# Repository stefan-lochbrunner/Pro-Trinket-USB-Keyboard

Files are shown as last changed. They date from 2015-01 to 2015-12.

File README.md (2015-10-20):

Pro-Trinket-USB-Keyboard
========================
A small device for programmable keyboard shortcuts.
For more infos please see [**HaD.io project page**](https://hackaday.io/project/3502-pro-trinket-usb-keyboard)

keyboard

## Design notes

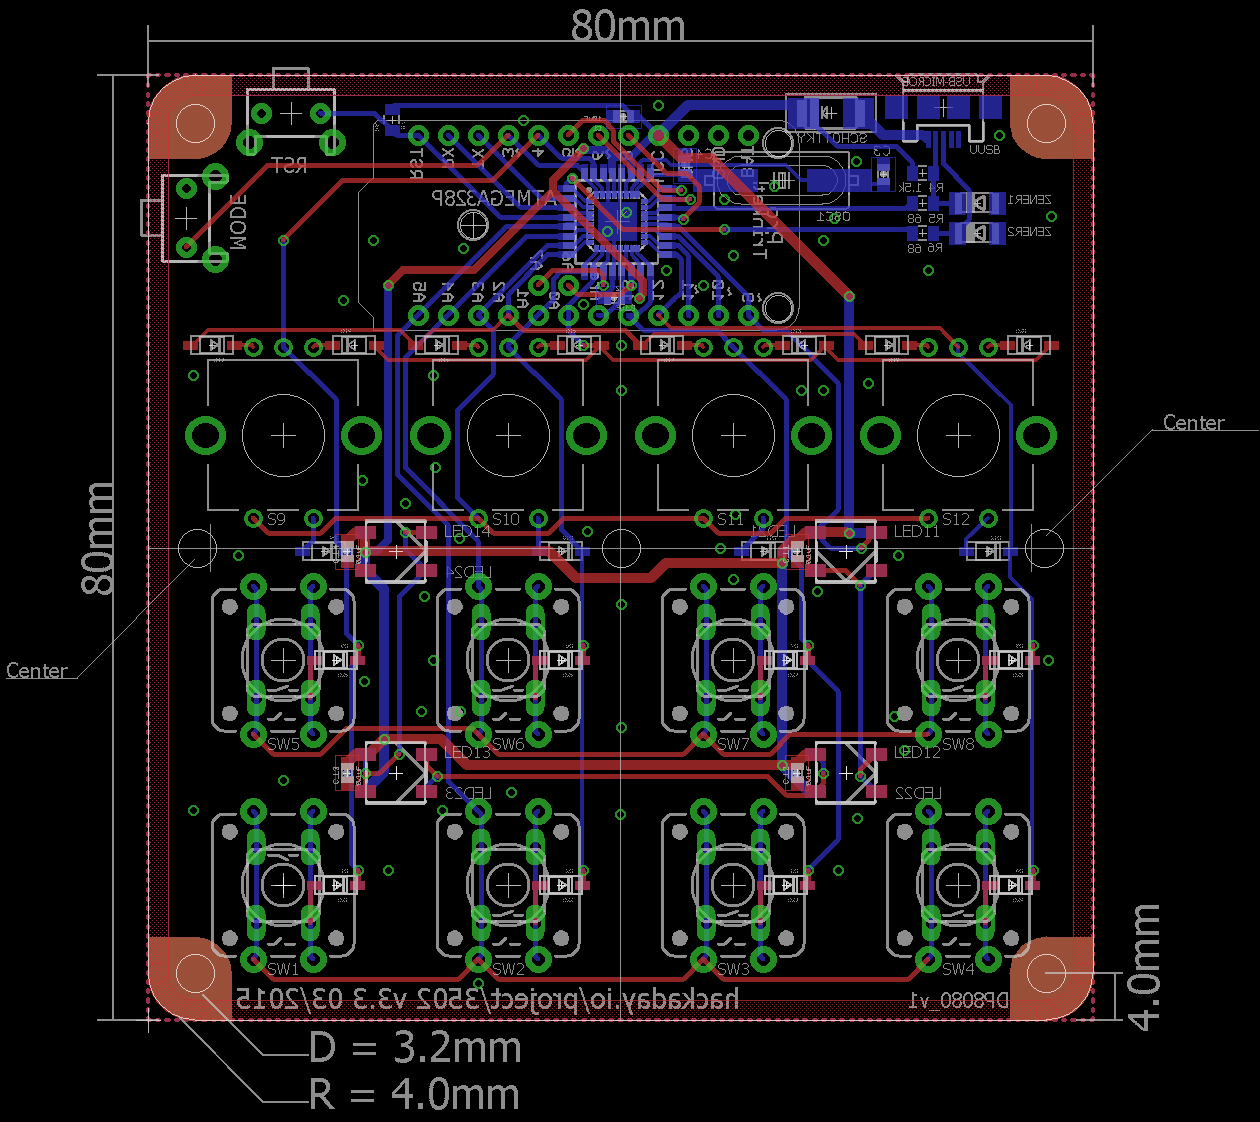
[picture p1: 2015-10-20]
Pro Trinket Keyboard/hw/schematics/Pro Trinket Keyboard V3.4.brd.png

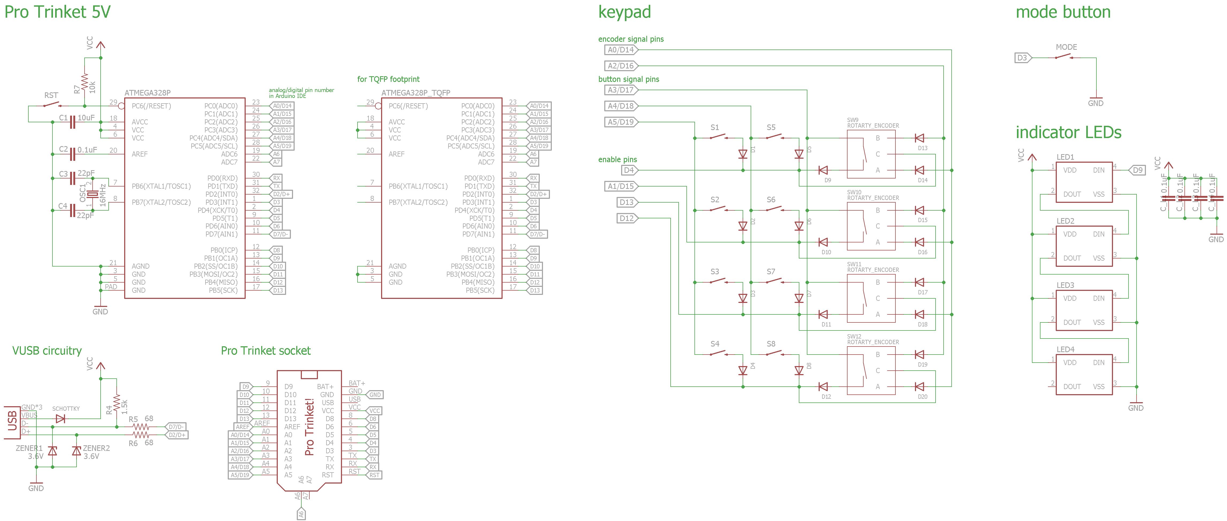
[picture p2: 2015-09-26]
Pro Trinket Keyboard/hw/schematics/Pro Trinket Keyboard V3.3.sch.png

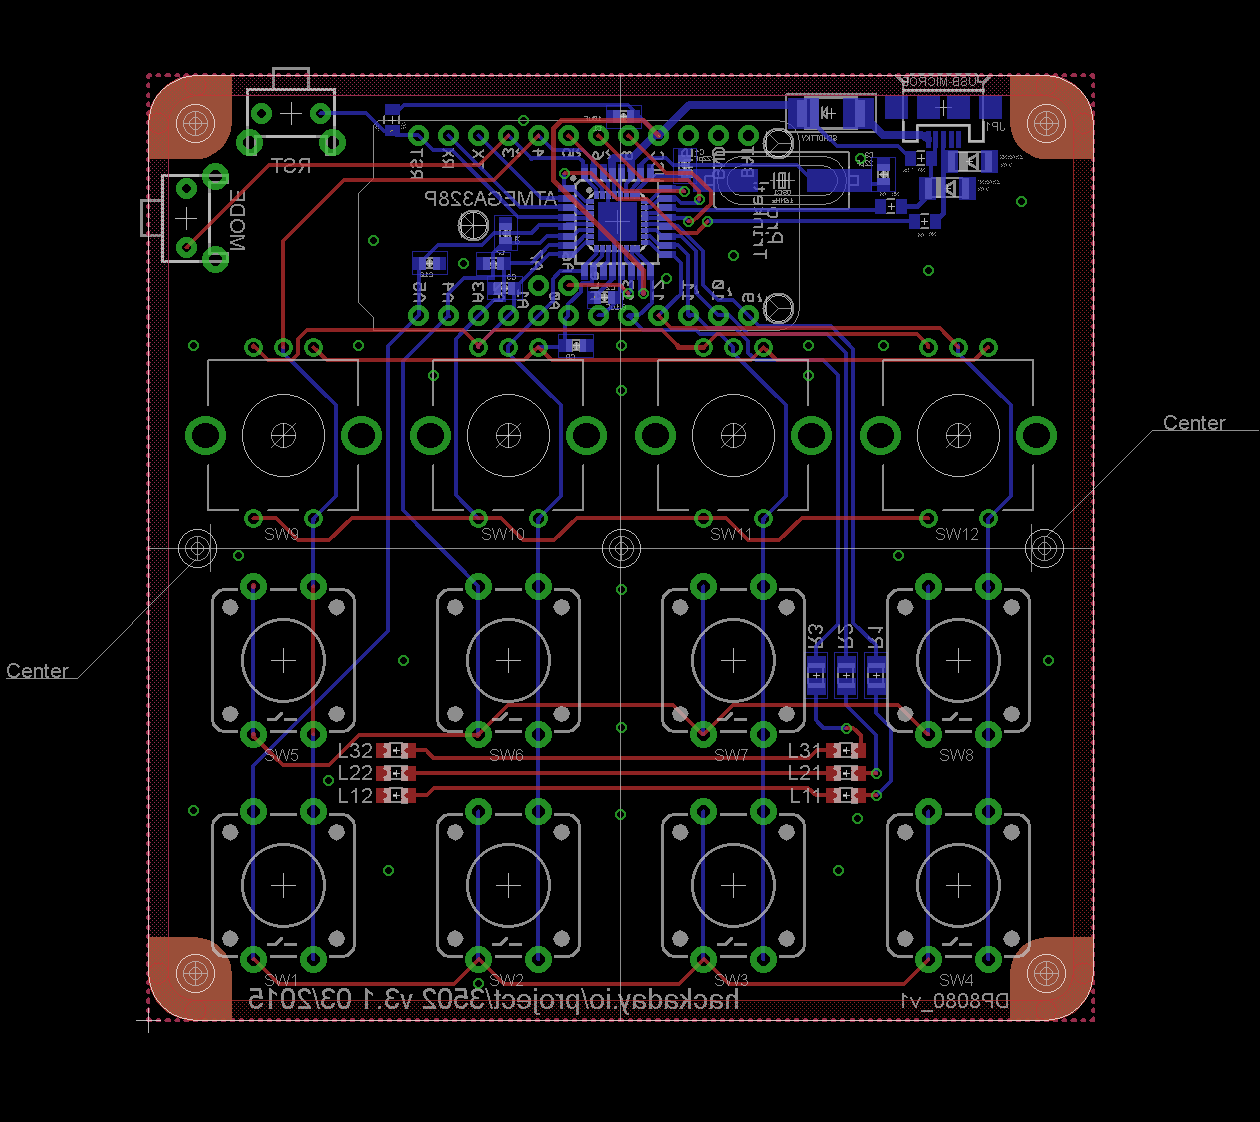
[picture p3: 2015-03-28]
Pro Trinket Keyboard/hw/schematics/Pro Trinket Keyboard V3.1.brd.png

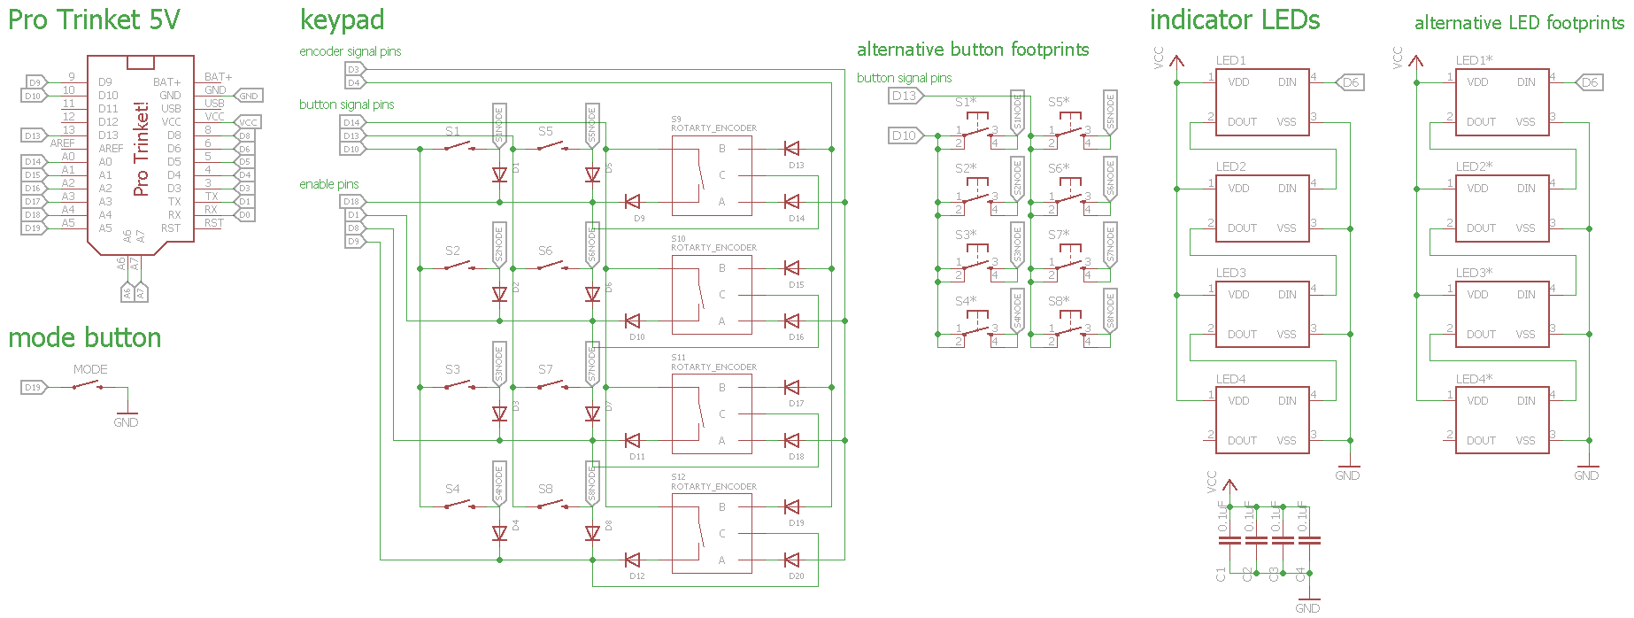
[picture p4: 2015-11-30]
Pro Trinket Keyboard/hw/schematics/Pro Trinket Keyboard V4.0.sch.png

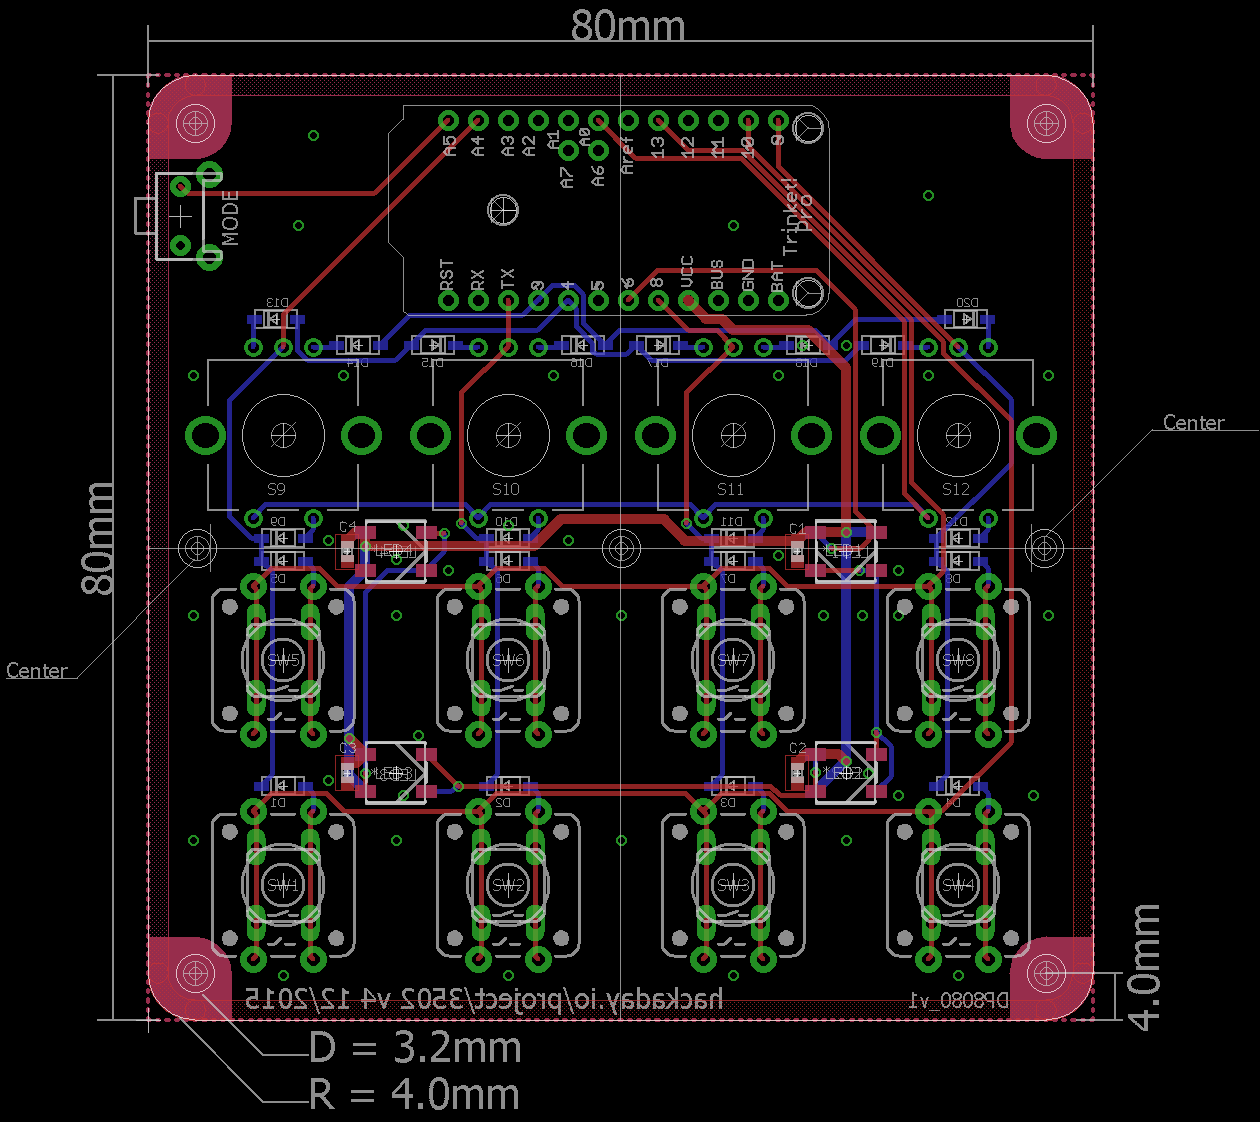
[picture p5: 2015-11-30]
Pro Trinket Keyboard/hw/schematics/Pro Trinket Keyboard V4.0.brd.png

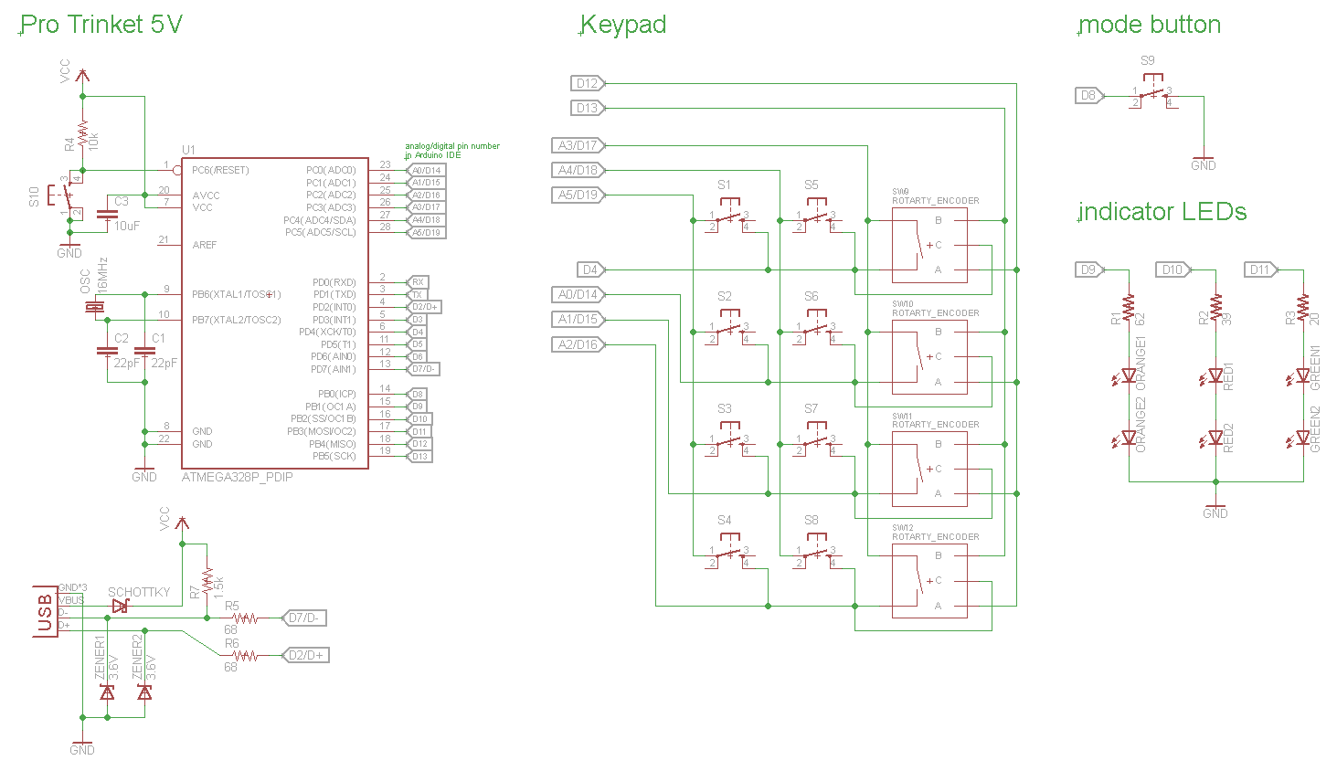
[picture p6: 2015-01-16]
Pro Trinket Keyboard/hw/schematics/Pro Trinket Keyboard V2.png

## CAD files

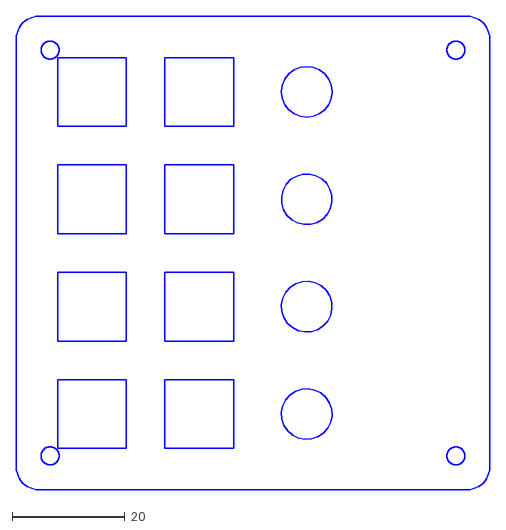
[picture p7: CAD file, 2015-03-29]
Pro Trinket Keyboard/hw/case/SoBv1-DP8080-case-top.dxf
84.0 x 84.0

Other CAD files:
Pro Trinket Keyboard/hw/case/SoBv1-DP8080-case-top.skp
Pro Trinket Keyboard/hw/case/SoBv1-DP8080-template.skp

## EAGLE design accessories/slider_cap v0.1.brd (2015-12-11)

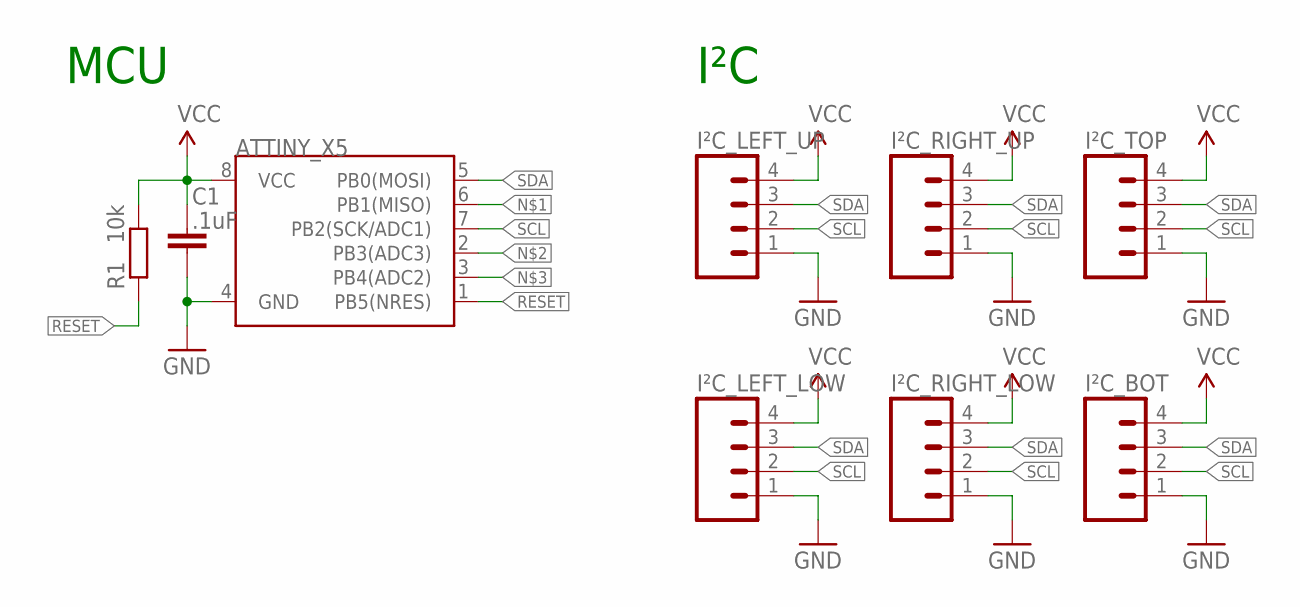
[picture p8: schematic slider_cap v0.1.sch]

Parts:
ATTINY_X5: ATTINY45TINY45-20-SMT; SO08-EIAJ
C1: .1uF; C805
I²C_BOT: M04PTH; 1X04
I²C_LEFT_LOW: M04PTH; 1X04
I²C_LEFT_UP: M04PTH; 1X04
I²C_RIGHT_LOW: M04PTH; 1X04
I²C_RIGHT_UP: M04PTH; 1X04
I²C_TOP: M04PTH; 1X04
R1: 10k; R805

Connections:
GND: ATTINY_X5.4 (GND), C1.2, I²C_BOT.1, I²C_LEFT_LOW.1, I²C_LEFT_UP.1, I²C_RIGHT_LOW.1, I²C_RIGHT_UP.1, I²C_TOP.1
RESET: ATTINY_X5.1 (PB5(NRES)), R1.1
SCL: ATTINY_X5.7 (PB2(SCK/ADC1)), I²C_BOT.2, I²C_LEFT_LOW.2, I²C_LEFT_UP.2, I²C_RIGHT_LOW.2, I²C_RIGHT_UP.2, I²C_TOP.2
SDA: ATTINY_X5.5 (PB0(MOSI)), I²C_BOT.3, I²C_LEFT_LOW.3, I²C_LEFT_UP.3, I²C_RIGHT_LOW.3, I²C_RIGHT_UP.3, I²C_TOP.3
VCC: ATTINY_X5.8 (VCC), C1.1, I²C_BOT.4, I²C_LEFT_LOW.4, I²C_LEFT_UP.4, I²C_RIGHT_LOW.4, I²C_RIGHT_UP.4, I²C_TOP.4, R1.2

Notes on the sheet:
I²C
MCU

Board: 2 copper layers, 9 parts (3 on the bottom side), 5 nets, no tracks yet.

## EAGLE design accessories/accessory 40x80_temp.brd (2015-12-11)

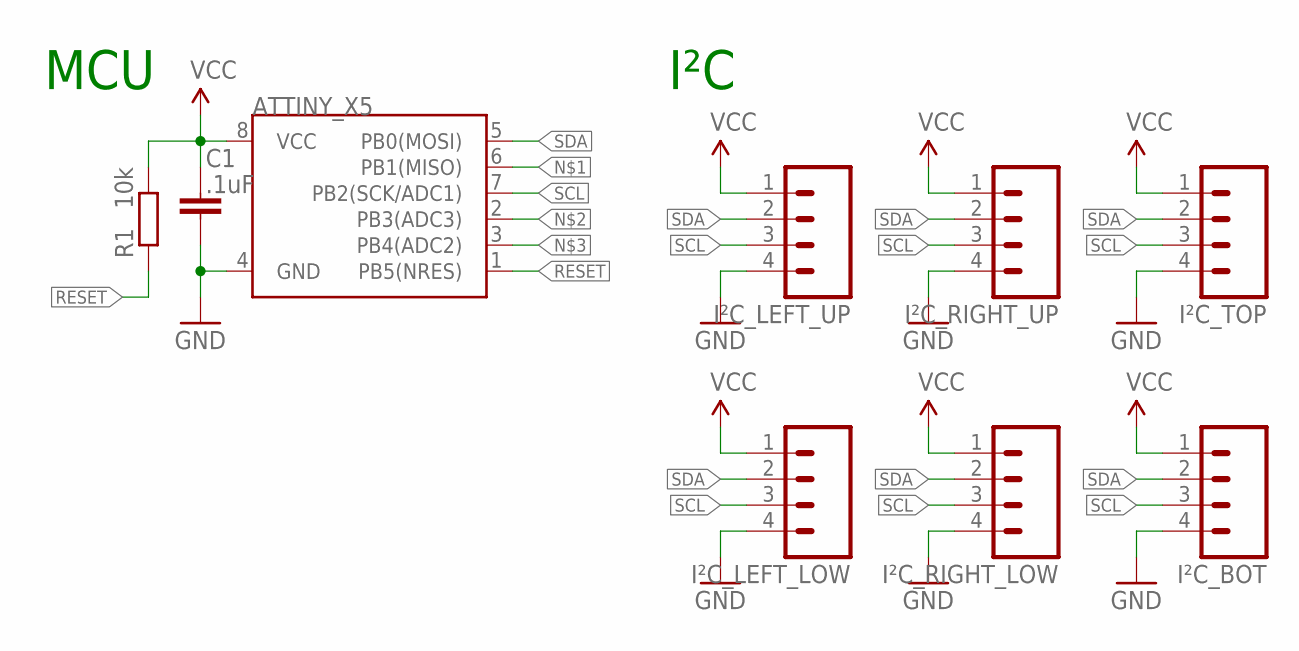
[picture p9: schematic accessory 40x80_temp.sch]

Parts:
ATTINY_X5: ATTINY45TINY45-20-SMT; SO08-EIAJ
C1: .1uF; C805
I²C_BOT: M04PTH; 1X04
I²C_LEFT_LOW: M04PTH; 1X04
I²C_LEFT_UP: M04PTH; 1X04
I²C_RIGHT_LOW: M04PTH; 1X04
I²C_RIGHT_UP: M04PTH; 1X04
I²C_TOP: M04PTH; 1X04
R1: 10k; R805

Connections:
GND: ATTINY_X5.4 (GND), C1.2, I²C_BOT.4, I²C_LEFT_LOW.4, I²C_LEFT_UP.4, I²C_RIGHT_LOW.4, I²C_RIGHT_UP.4, I²C_TOP.4
RESET: ATTINY_X5.1 (PB5(NRES)), R1.1
SCL: ATTINY_X5.7 (PB2(SCK/ADC1)), I²C_BOT.3, I²C_LEFT_LOW.3, I²C_LEFT_UP.3, I²C_RIGHT_LOW.3, I²C_RIGHT_UP.3, I²C_TOP.3
SDA: ATTINY_X5.5 (PB0(MOSI)), I²C_BOT.2, I²C_LEFT_LOW.2, I²C_LEFT_UP.2, I²C_RIGHT_LOW.2, I²C_RIGHT_UP.2, I²C_TOP.2
VCC: ATTINY_X5.8 (VCC), C1.1, I²C_BOT.1, I²C_LEFT_LOW.1, I²C_LEFT_UP.1, I²C_RIGHT_LOW.1, I²C_RIGHT_UP.1, I²C_TOP.1, R1.2

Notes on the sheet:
I²C
MCU

Board: 2 copper layers, 9 parts (3 on the bottom side), 5 nets, no tracks yet.

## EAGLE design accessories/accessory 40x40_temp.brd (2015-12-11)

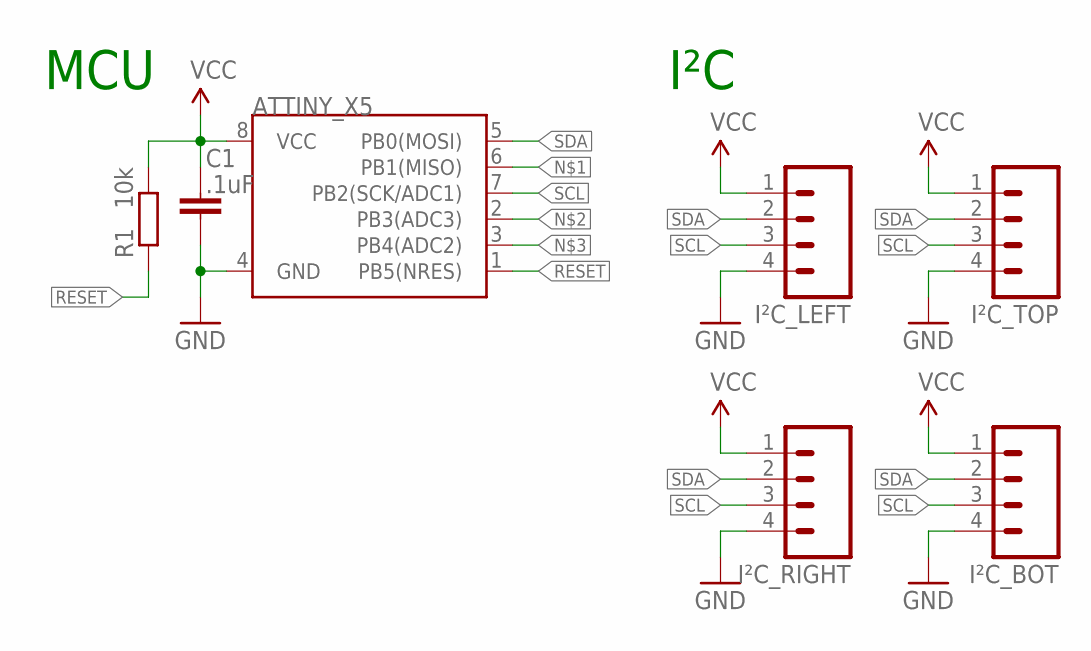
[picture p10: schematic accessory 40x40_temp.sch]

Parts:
ATTINY_X5: ATTINY45TINY45-20-SMT; SO08-EIAJ
C1: .1uF; C805
I²C_BOT: M04PTH; 1X04
I²C_LEFT: M04PTH; 1X04
I²C_RIGHT: M04PTH; 1X04
I²C_TOP: M04PTH; 1X04
R1: 10k; R805

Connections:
GND: ATTINY_X5.4 (GND), C1.2, I²C_BOT.4, I²C_LEFT.4, I²C_RIGHT.4, I²C_TOP.4
RESET: ATTINY_X5.1 (PB5(NRES)), R1.1
SCL: ATTINY_X5.7 (PB2(SCK/ADC1)), I²C_BOT.3, I²C_LEFT.3, I²C_RIGHT.3, I²C_TOP.3
SDA: ATTINY_X5.5 (PB0(MOSI)), I²C_BOT.2, I²C_LEFT.2, I²C_RIGHT.2, I²C_TOP.2
VCC: ATTINY_X5.8 (VCC), C1.1, I²C_BOT.1, I²C_LEFT.1, I²C_RIGHT.1, I²C_TOP.1, R1.2

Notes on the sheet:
I²C
MCU

Board: 2 copper layers, 7 parts (3 on the bottom side), 5 nets, no tracks yet.

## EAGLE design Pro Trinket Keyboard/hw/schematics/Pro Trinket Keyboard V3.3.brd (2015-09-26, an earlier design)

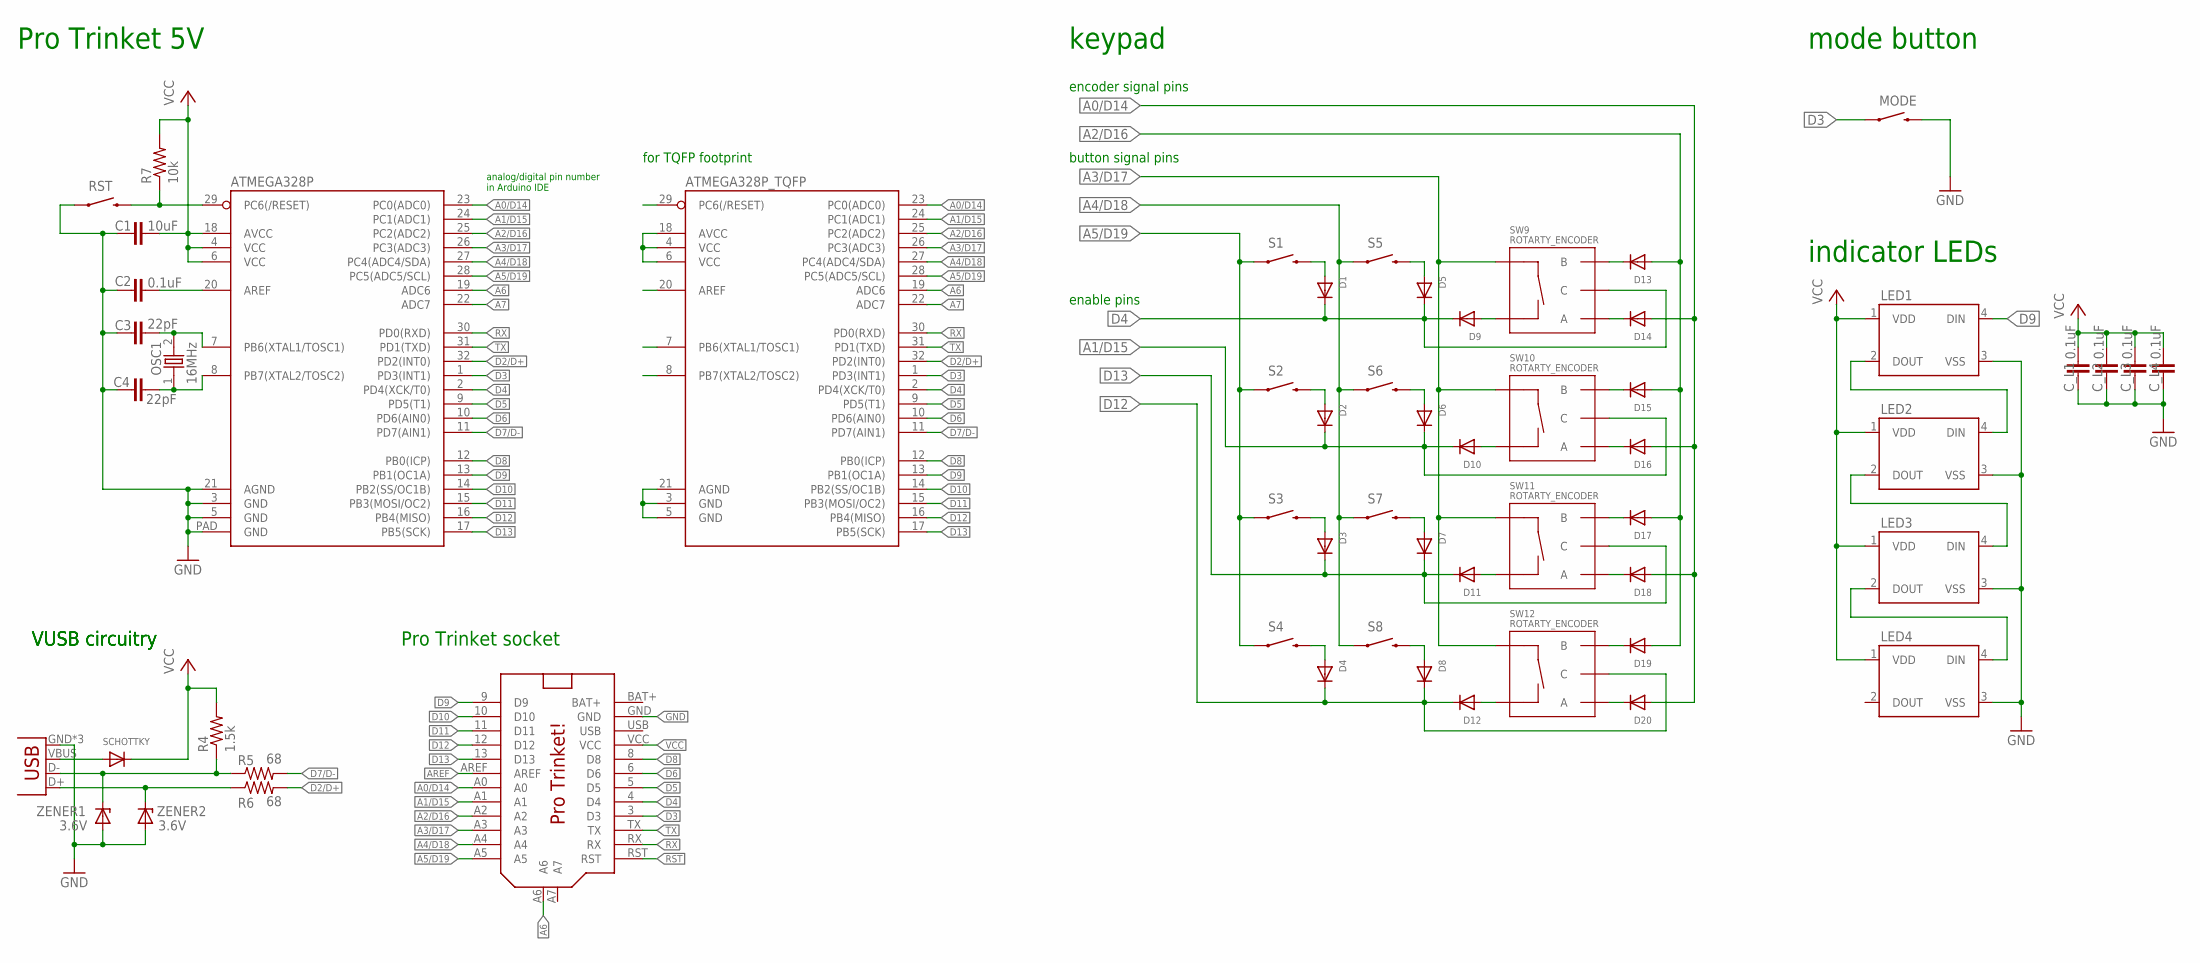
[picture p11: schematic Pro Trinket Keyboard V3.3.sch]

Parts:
ATMEGA328P: ATMEGA328P_MLFMLF32; MLF32-PAD
ATMEGA328P_TQFP: ATMEGA328P_TQFP; TQFP32-08
C1: 10uF; 0603-CAP
C2: 0.1uF; 0603-CAP
C3, C4: 22pF; 0603-CAP
C_L1, C_L2, C_L3, C_L4: 0.1uF; 0603-CAP
D1, D2, D3, D4, D5, D6, D7, D8, D9, D10, D11, D12, D13, D14, D15, D16, D17, D18, D19, D20: DIODESOD-123; SOD-123
JP1: USB-MICROB
LED1, LED2, LED3, LED4: WS2812B
MODE: SWITCH-MOMENTARY-2SIDE_EZ; TACTILE-PTH-SIDEEZ
OSC1: 16MHz; HC-49U
R4: 1.5k; 0805
R5, R6: 68; 0805
R7: 10k; 0805
RST: SWITCH-MOMENTARY-2SIDE_EZ; TACTILE-PTH-SIDEEZ
S1, S2, S3, S4, S5, S6, S7, S8: SWITCH-MOMENTARY-212MM; TACTILE-PTH-12MM
SCHOTTKY: DIODESMA; SMADIODE
SW9, SW10, SW11, SW12: ROTARTY_ENCODER; ROTARY_ENC_PLAIN
U$2: PRO_TRINKET; PROTRINKET
ZENER1, ZENER2: 3.6V; SOD80C

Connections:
A0/D14: ATMEGA328P.23 (PC0(ADC0)), ATMEGA328P_TQFP.23 (PC0(ADC0)), D14.A, D16.A, D18.A, D20.A, U$2.A0
A1/D15: ATMEGA328P.24 (PC1(ADC1)), ATMEGA328P_TQFP.24 (PC1(ADC1)), D2.C, D6.C, D10.C, SW10.C, U$2.A1
A2/D16: ATMEGA328P.25 (PC2(ADC2)), ATMEGA328P_TQFP.25 (PC2(ADC2)), D13.A, D15.A, D17.A, D19.A, U$2.A2
A3/D17: ATMEGA328P.26 (PC3(ADC3)), ATMEGA328P_TQFP.26 (PC3(ADC3)), SW9.SW+, SW10.SW+, SW11.SW+, SW12.SW+, U$2.A3
A4/D18: ATMEGA328P.27 (PC4(ADC4/SDA)), ATMEGA328P_TQFP.27 (PC4(ADC4/SDA)), S5.1, S5.2 (1), S6.1, S6.2 (1), S7.1, S7.2 (1), S8.1, S8.2 (1), U$2.A4
A5/D19: ATMEGA328P.28 (PC5(ADC5/SCL)), ATMEGA328P_TQFP.28 (PC5(ADC5/SCL)), S1.1, S1.2 (1), S2.1, S2.2 (1), S3.1, S3.2 (1), S4.1, S4.2 (1), U$2.A5
A6: ATMEGA328P.19 (ADC6), ATMEGA328P_TQFP.19 (ADC6), U$2.A6
A7: ATMEGA328P.22 (ADC7), ATMEGA328P_TQFP.22 (ADC7)
AREF: ATMEGA328P.20 (AREF), ATMEGA328P_TQFP.20 (AREF), C2.2, U$2.AREF
BAT+: U$2.BAT+
D2/D+: ATMEGA328P.32 (PD2(INT0)), ATMEGA328P_TQFP.32 (PD2(INT0)), R6.2
D3: ATMEGA328P.1 (PD3(INT1)), ATMEGA328P_TQFP.1 (PD3(INT1)), MODE.1, U$2.3 (D3)
D4: ATMEGA328P.2 (PD4(XCK/T0)), ATMEGA328P_TQFP.2 (PD4(XCK/T0)), D1.C, D5.C, D9.C, SW9.C, U$2.4 (D4)
D5: ATMEGA328P.9 (PD5(T1)), ATMEGA328P_TQFP.9 (PD5(T1)), U$2.5 (D5)
D6: ATMEGA328P.10 (PD6(AIN0)), ATMEGA328P_TQFP.10 (PD6(AIN0)), U$2.6 (D6)
D7/D-: ATMEGA328P.11 (PD7(AIN1)), ATMEGA328P_TQFP.11 (PD7(AIN1)), R5.2
D8: ATMEGA328P.12 (PB0(ICP)), ATMEGA328P_TQFP.12 (PB0(ICP)), U$2.8 (D8)
D9: ATMEGA328P.13 (PB1(OC1A)), ATMEGA328P_TQFP.13 (PB1(OC1A)), LED1.4 (DIN), U$2.9 (D9)
D10: ATMEGA328P.14 (PB2(SS/OC1B)), ATMEGA328P_TQFP.14 (PB2(SS/OC1B)), U$2.10 (D10)
D11: ATMEGA328P.15 (PB3(MOSI/OC2)), ATMEGA328P_TQFP.15 (PB3(MOSI/OC2)), U$2.11 (D11)
D12: ATMEGA328P.16 (PB4(MISO)), ATMEGA328P_TQFP.16 (PB4(MISO)), D4.C, D8.C, D12.C, SW12.C, U$2.12 (D12)
D13: ATMEGA328P.17 (PB5(SCK)), ATMEGA328P_TQFP.17 (PB5(SCK)), D3.C, D7.C, D11.C, SW11.C, U$2.13 (D13)
GND: ATMEGA328P.3 (GND), ATMEGA328P.5 (GND), ATMEGA328P.21 (AGND), ATMEGA328P.PAD (GND), ATMEGA328P_TQFP.3 (GND), ATMEGA328P_TQFP.5 (GND), ATMEGA328P_TQFP.21 (AGND), C1.1, C2.1, C3.1, C4.2, C_L1.1, C_L2.1, C_L3.1, C_L4.1, JP1.GND, JP1.MT1 (GND), JP1.MT2 (GND), LED1.3 (VSS), LED2.3 (VSS), LED3.3 (VSS), LED4.3 (VSS), MODE.2, RST.1, U$2.GND, ZENER1.A, ZENER2.A
unnamed: LED1.2 (DOUT), LED2.4 (DIN)
unnamed: LED2.2 (DOUT), LED3.4 (DIN)
unnamed: LED3.2 (DOUT), LED4.4 (DIN)
unnamed: JP1.VBUS, SCHOTTKY.A
unnamed: JP1.D-, R4.1, R5.1, ZENER1.C
unnamed: JP1.D+, R6.1, ZENER2.C
unnamed: D1.A, S1.3 (2), S1.4 (2)
unnamed: D2.A, S2.3 (2), S2.4 (2)
unnamed: D5.A, S5.3 (2), S5.4 (2)
unnamed: D6.A, S6.3 (2), S6.4 (2)
unnamed: D7.A, S7.3 (2), S7.4 (2)
unnamed: D3.A, S3.3 (2), S3.4 (2)
unnamed: D4.A, S4.3 (2), S4.4 (2)
unnamed: D8.A, S8.3 (2), S8.4 (2)
unnamed: D10.A, SW10.SW-
unnamed: D9.A, SW9.SW-
unnamed: D11.A, SW11.SW-
unnamed: D20.C, SW12.A
unnamed: D19.C, SW12.B
unnamed: D18.C, SW11.A
unnamed: D12.A, SW12.SW-
unnamed: D16.C, SW10.A
unnamed: D15.C, SW10.B
unnamed: D14.C, SW9.A
unnamed: D13.C, SW9.B
unnamed: D17.C, SW11.B
RST: ATMEGA328P.29 (PC6(/RESET)), ATMEGA328P_TQFP.29 (PC6(/RESET)), R7.1, RST.2, U$2.RST
RX: ATMEGA328P.30 (PD0(RXD)), ATMEGA328P_TQFP.30 (PD0(RXD)), U$2.RX
TX: ATMEGA328P.31 (PD1(TXD)), ATMEGA328P_TQFP.31 (PD1(TXD)), U$2.TX
USB: U$2.USB
VCC: ATMEGA328P.4 (VCC), ATMEGA328P.6 (VCC), ATMEGA328P.18 (AVCC), ATMEGA328P_TQFP.4 (VCC), ATMEGA328P_TQFP.6 (VCC), ATMEGA328P_TQFP.18 (AVCC), C1.2, C_L1.2, C_L2.2, C_L3.2, C_L4.2, LED1.1 (VDD), LED2.1 (VDD), LED3.1 (VDD), LED4.1 (VDD), R4.2, R7.2, SCHOTTKY.C, U$2.VCC
XTAL1: ATMEGA328P.7 (PB6(XTAL1/TOSC1)), ATMEGA328P_TQFP.7 (PB6(XTAL1/TOSC1)), C3.2, OSC1.2
XTAL2: ATMEGA328P.8 (PB7(XTAL2/TOSC2)), ATMEGA328P_TQFP.8 (PB7(XTAL2/TOSC2)), C4.1, OSC1.1

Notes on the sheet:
keypad
mode button
indicator LEDs
Pro Trinket 5V
analog/digital pin number in Arduino IDE
VUSB circuitry
Pro Trinket socket
enable pins
encoder signal pins
button signal pins
for TQFP footprint

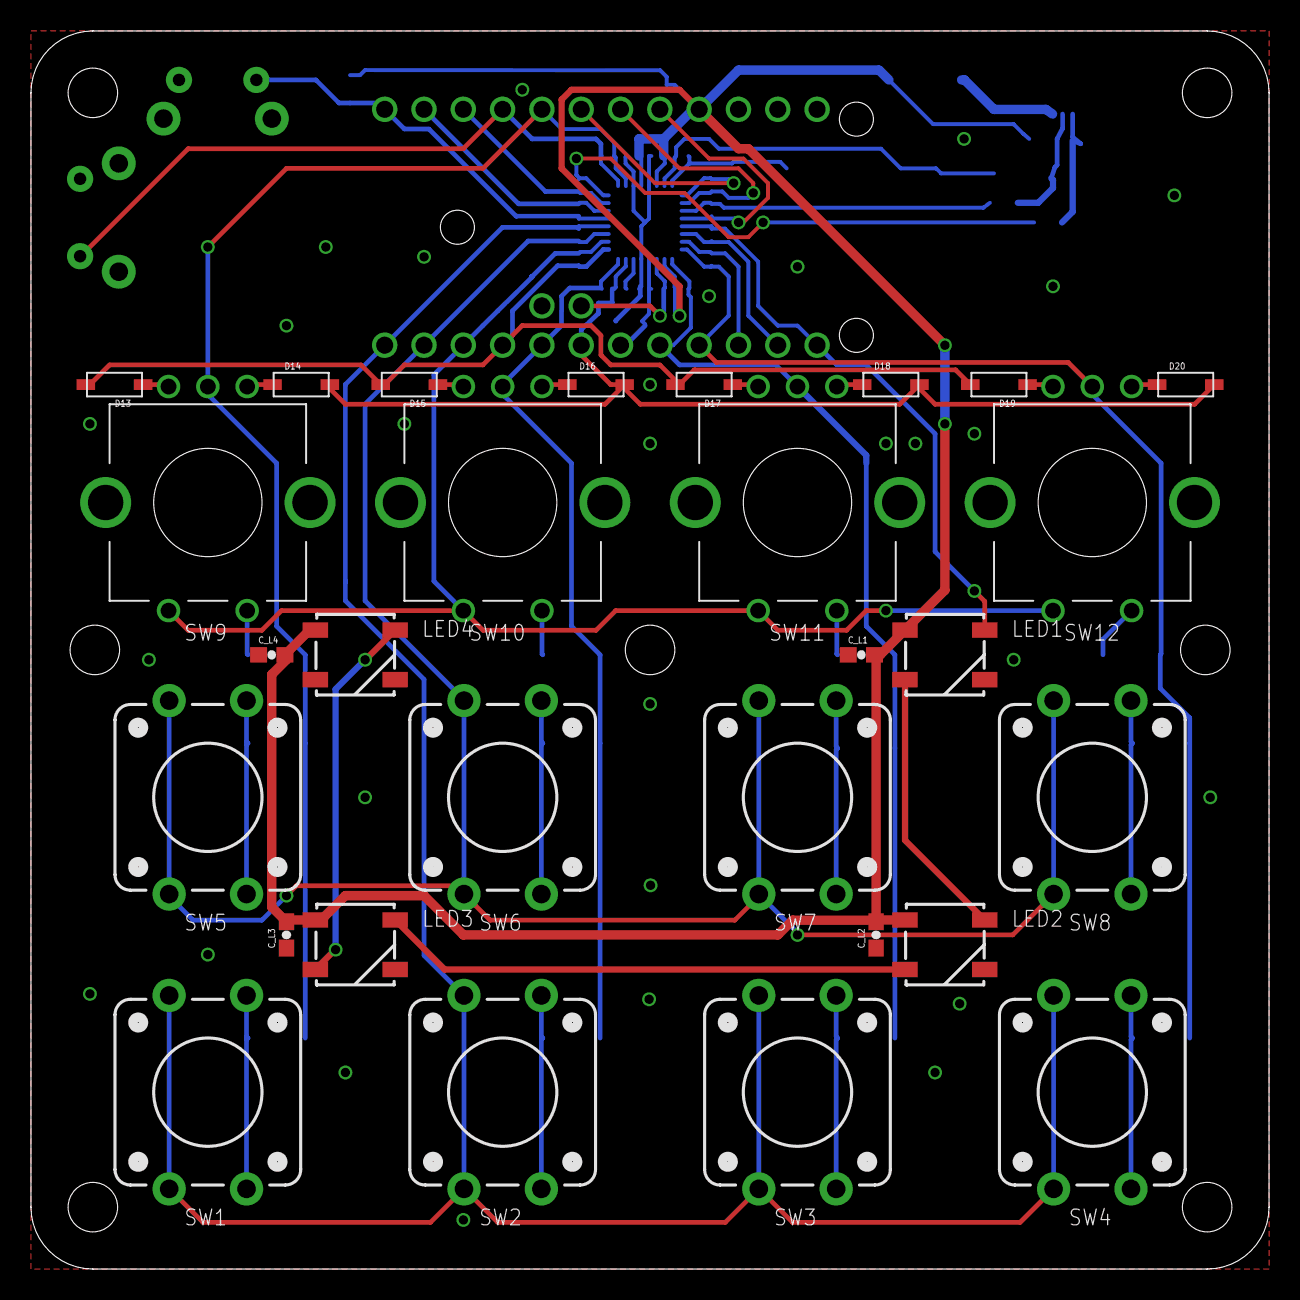
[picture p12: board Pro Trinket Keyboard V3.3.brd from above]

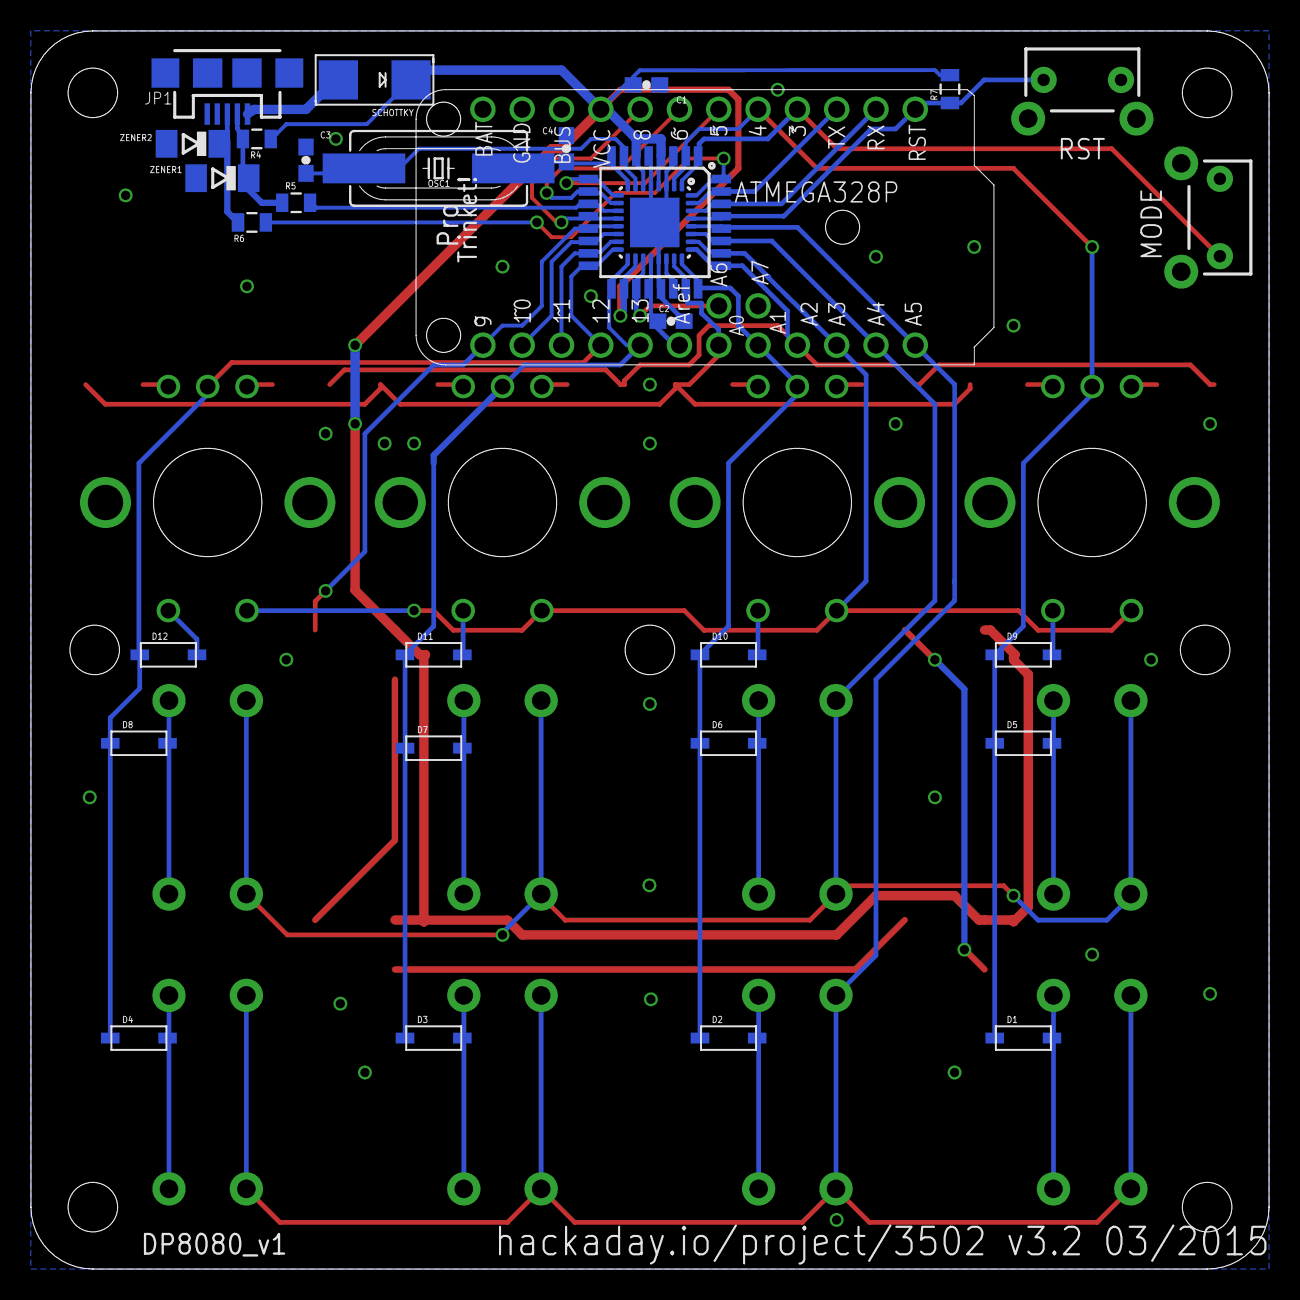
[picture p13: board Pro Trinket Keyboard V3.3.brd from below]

Board: 2 copper layers, 80.0 x 80.0 mm, 59 parts (30 on the bottom side), 54 nets.

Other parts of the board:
U$1: DP8080_V1

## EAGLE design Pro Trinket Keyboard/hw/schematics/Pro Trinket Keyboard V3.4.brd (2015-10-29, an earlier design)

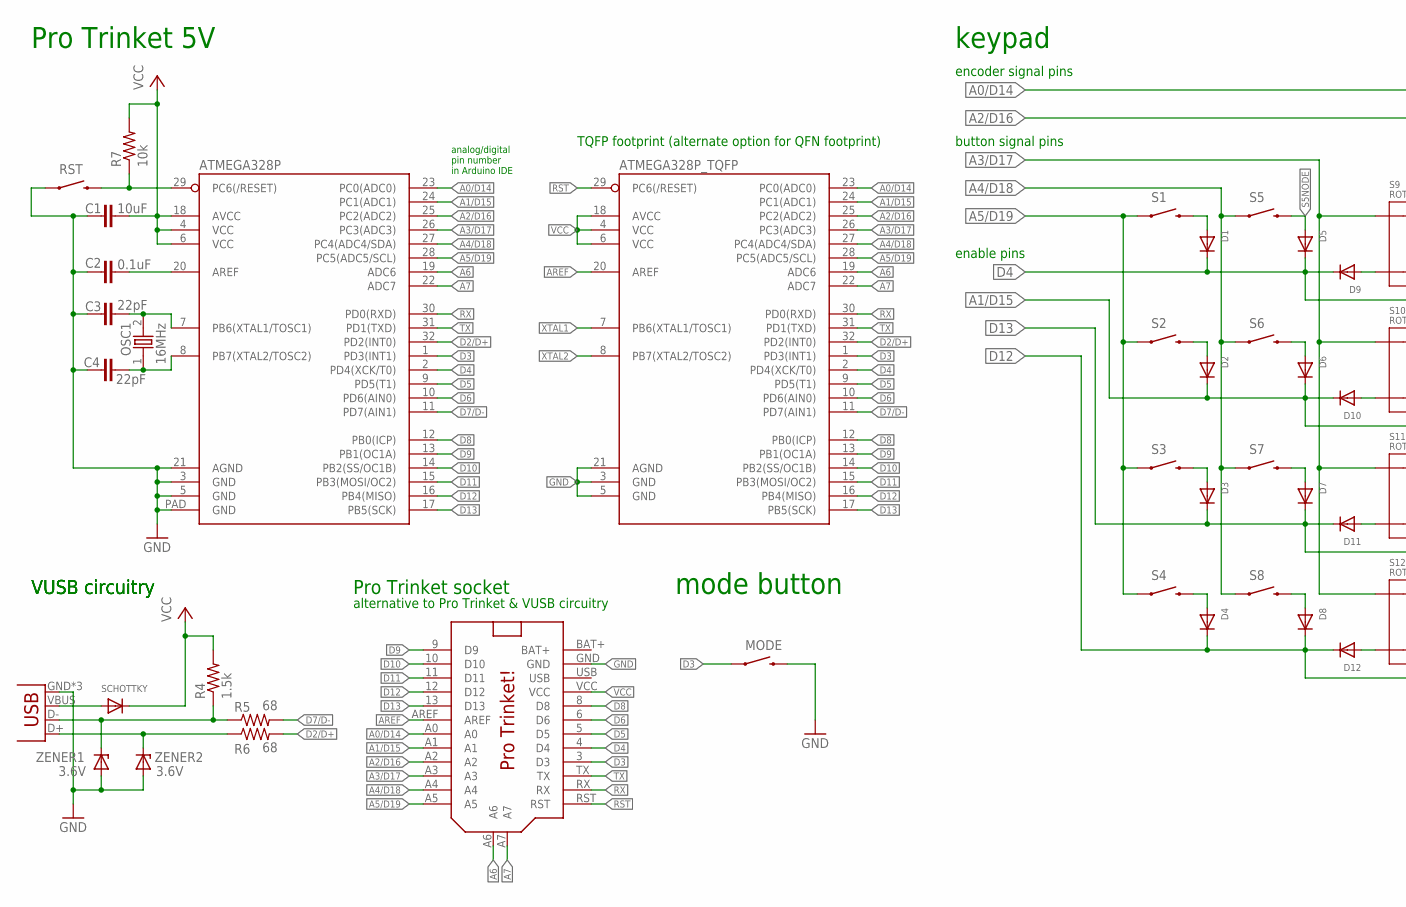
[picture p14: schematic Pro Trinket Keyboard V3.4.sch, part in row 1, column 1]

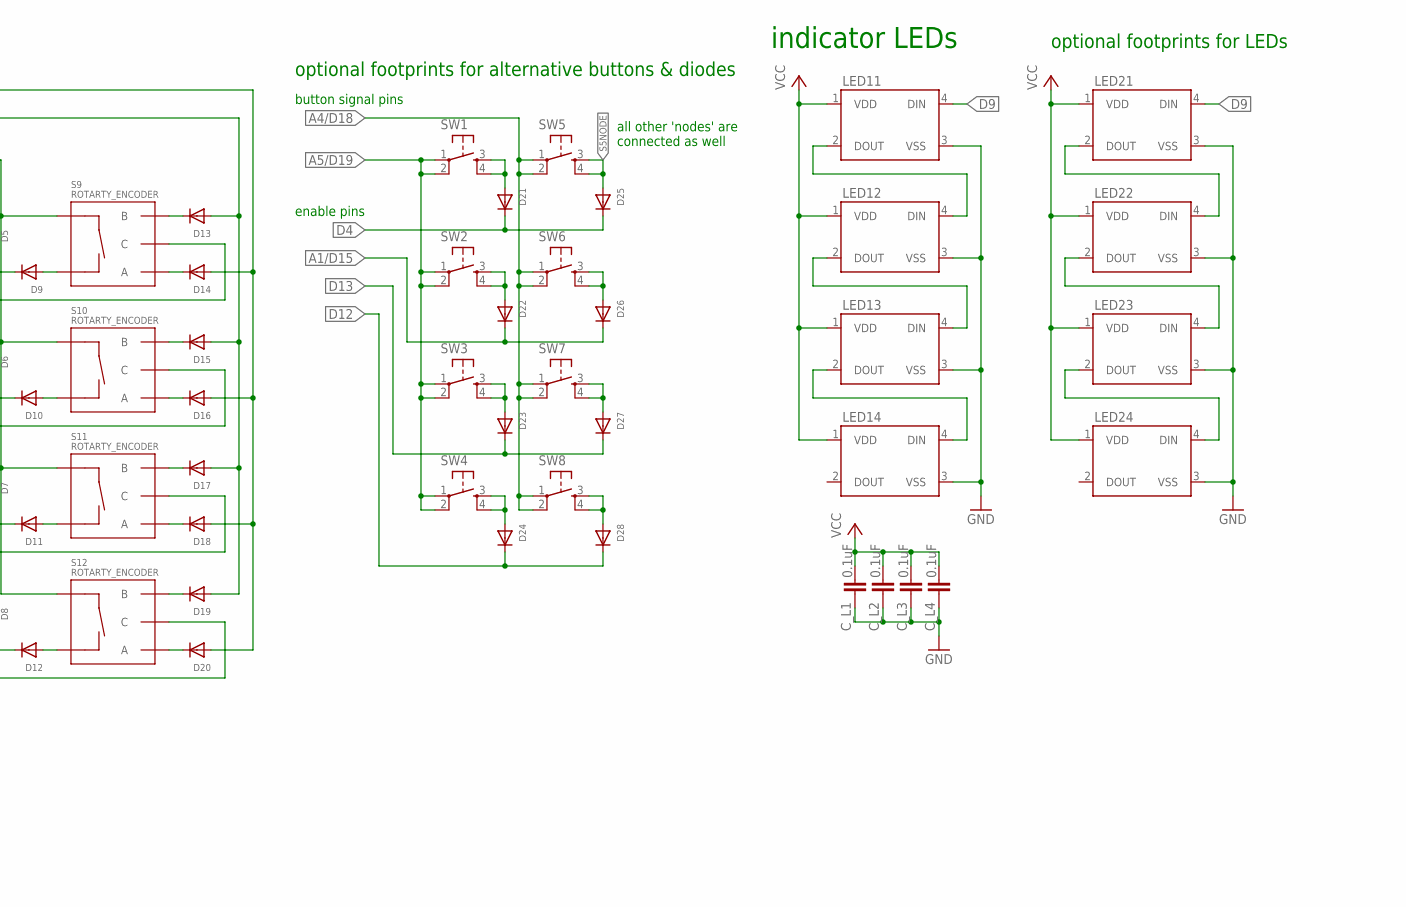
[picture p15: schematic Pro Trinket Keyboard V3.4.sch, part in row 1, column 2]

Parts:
ATMEGA328P: ATMEGA328P_MLFMLF32; MLF32-PAD
ATMEGA328P_TQFP: ATMEGA328P_TQFP; TQFP32-08
C1: 10uF; 0603-CAP
C2: 0.1uF; 0603-CAP
C3, C4: 22pF; 0603-CAP
C_L1, C_L2, C_L3, C_L4: 0.1uF; 0603-CAP
D1, D2, D3, D4, D5, D6, D7, D8, D9, D10, D11, D12, D13, D14, D15, D16, D17, D18, D19, D20, D21, D22, D23, D24, D25, D26, D27, D28: DIODESOD-123; SOD-123
LED11, LED12, LED13, LED14, LED21, LED22, LED23, LED24: WS2812B
MODE: SWITCH-MOMENTARY-2SIDE_EZ; TACTILE-PTH-SIDEEZ
OSC1: 16MHz; HC-49U
R4: 1.5k; 0805
R5, R6: 68; 0805
R7: 10k; 0805
RST: SWITCH-MOMENTARY-2SIDE_EZ; TACTILE-PTH-SIDEEZ
S1, S2, S3, S4, S5, S6, S7, S8: SWITCH-MOMENTARY-212MM; TACTILE-PTH-12MM
S9, S10, S11, S12: ROTARTY_ENCODER; ROTARY_ENC_PLAIN
SCHOTTKY: DIODESMA; SMADIODE
SW1, SW2, SW3, SW4, SW5, SW6, SW7, SW8: TACTILE-SWITCH-PTH; TAC-SWITCH-PTH
U$2: PRO_TRINKET; PROTRINKET
UUSB: USB-MICROB
ZENER1, ZENER2: 3.6V; SOD80C

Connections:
A0/D14: ATMEGA328P.23 (PC0(ADC0)), ATMEGA328P_TQFP.23 (PC0(ADC0)), D14.A, D16.A, D18.A, D20.A, U$2.A0
A1/D15: ATMEGA328P.24 (PC1(ADC1)), ATMEGA328P_TQFP.24 (PC1(ADC1)), D2.C, D6.C, D10.C, D22.C, D26.C, S10.C, U$2.A1
A2/D16: ATMEGA328P.25 (PC2(ADC2)), ATMEGA328P_TQFP.25 (PC2(ADC2)), D13.A, D15.A, D17.A, D19.A, U$2.A2
A3/D17: ATMEGA328P.26 (PC3(ADC3)), ATMEGA328P_TQFP.26 (PC3(ADC3)), S9.SW+, S10.SW+, S11.SW+, S12.SW+, U$2.A3
A4/D18: ATMEGA328P.27 (PC4(ADC4/SDA)), ATMEGA328P_TQFP.27 (PC4(ADC4/SDA)), S5.1, S5.2 (1), S6.1, S6.2 (1), S7.1, S7.2 (1), S8.1, S8.2 (1), SW5.1, SW5.2, SW6.1, SW6.2, SW7.1, SW7.2, SW8.1, SW8.2, U$2.A4
A5/D19: ATMEGA328P.28 (PC5(ADC5/SCL)), ATMEGA328P_TQFP.28 (PC5(ADC5/SCL)), S1.1, S1.2 (1), S2.1, S2.2 (1), S3.1, S3.2 (1), S4.1, S4.2 (1), SW1.1, SW1.2, SW2.1, SW2.2, SW3.1, SW3.2, SW4.1, SW4.2, U$2.A5
A6: ATMEGA328P.19 (ADC6), ATMEGA328P_TQFP.19 (ADC6), U$2.A6
A7: ATMEGA328P.22 (ADC7), ATMEGA328P_TQFP.22 (ADC7), U$2.A7
AREF: ATMEGA328P.20 (AREF), ATMEGA328P_TQFP.20 (AREF), C2.2, U$2.AREF
BAT+: U$2.BAT+
D2/D+: ATMEGA328P.32 (PD2(INT0)), ATMEGA328P_TQFP.32 (PD2(INT0)), R6.2
D3: ATMEGA328P.1 (PD3(INT1)), ATMEGA328P_TQFP.1 (PD3(INT1)), MODE.1, U$2.3 (D3)
D4: ATMEGA328P.2 (PD4(XCK/T0)), ATMEGA328P_TQFP.2 (PD4(XCK/T0)), D1.C, D5.C, D9.C, D21.C, D25.C, S9.C, U$2.4 (D4)
D5: ATMEGA328P.9 (PD5(T1)), ATMEGA328P_TQFP.9 (PD5(T1)), U$2.5 (D5)
D6: ATMEGA328P.10 (PD6(AIN0)), ATMEGA328P_TQFP.10 (PD6(AIN0)), U$2.6 (D6)
D7/D-: ATMEGA328P.11 (PD7(AIN1)), ATMEGA328P_TQFP.11 (PD7(AIN1)), R5.2
D8: ATMEGA328P.12 (PB0(ICP)), ATMEGA328P_TQFP.12 (PB0(ICP)), U$2.8 (D8)
D9: ATMEGA328P.13 (PB1(OC1A)), ATMEGA328P_TQFP.13 (PB1(OC1A)), LED11.4 (DIN), LED21.4 (DIN), U$2.9 (D9)
D10: ATMEGA328P.14 (PB2(SS/OC1B)), ATMEGA328P_TQFP.14 (PB2(SS/OC1B)), U$2.10 (D10)
D11: ATMEGA328P.15 (PB3(MOSI/OC2)), ATMEGA328P_TQFP.15 (PB3(MOSI/OC2)), U$2.11 (D11)
D12: ATMEGA328P.16 (PB4(MISO)), ATMEGA328P_TQFP.16 (PB4(MISO)), D4.C, D8.C, D12.C, D24.C, D28.C, S12.C, U$2.12 (D12)
D13: ATMEGA328P.17 (PB5(SCK)), ATMEGA328P_TQFP.17 (PB5(SCK)), D3.C, D7.C, D11.C, D23.C, D27.C, S11.C, U$2.13 (D13)
GND: ATMEGA328P.3 (GND), ATMEGA328P.5 (GND), ATMEGA328P.21 (AGND), ATMEGA328P.PAD (GND), ATMEGA328P_TQFP.3 (GND), ATMEGA328P_TQFP.5 (GND), ATMEGA328P_TQFP.21 (AGND), C1.1, C2.1, C3.1, C4.2, C_L1.1, C_L2.1, C_L3.1, C_L4.1, LED11.3 (VSS), LED12.3 (VSS), LED13.3 (VSS), LED14.3 (VSS), LED21.3 (VSS), LED22.3 (VSS), LED23.3 (VSS), LED24.3 (VSS), MODE.2, RST.1, U$2.GND, UUSB.GND, UUSB.MT1 (GND), UUSB.MT2 (GND), ZENER1.A, ZENER2.A
L1NODE: LED11.2 (DOUT), LED12.4 (DIN), LED21.2 (DOUT), LED22.4 (DIN)
L2NODE: LED12.2 (DOUT), LED13.4 (DIN), LED22.2 (DOUT), LED23.4 (DIN)
L3NODE: LED13.2 (DOUT), LED14.4 (DIN), LED23.2 (DOUT), LED24.4 (DIN)
unnamed: SCHOTTKY.A, UUSB.VBUS
unnamed: R4.1, R5.1, UUSB.D-, ZENER1.C
unnamed: R6.1, UUSB.D+, ZENER2.C
unnamed: D10.A, S10.SW-
unnamed: D9.A, S9.SW-
unnamed: D11.A, S11.SW-
unnamed: D20.C, S12.A
unnamed: D19.C, S12.B
unnamed: D18.C, S11.A
unnamed: D12.A, S12.SW-
unnamed: D16.C, S10.A
unnamed: D15.C, S10.B
unnamed: D14.C, S9.A
unnamed: D13.C, S9.B
unnamed: D17.C, S11.B
RST: ATMEGA328P.29 (PC6(/RESET)), ATMEGA328P_TQFP.29 (PC6(/RESET)), R7.1, RST.2, U$2.RST
RX: ATMEGA328P.30 (PD0(RXD)), ATMEGA328P_TQFP.30 (PD0(RXD)), U$2.RX
S1NODE: D1.A, D21.A, S1.3 (2), S1.4 (2), SW1.3, SW1.4
S2NODE: D2.A, D22.A, S2.3 (2), S2.4 (2), SW2.3, SW2.4
S3NODE: D3.A, D23.A, S3.3 (2), S3.4 (2), SW3.3, SW3.4
S4NODE: D4.A, D24.A, S4.3 (2), S4.4 (2), SW4.3, SW4.4
S5NODE: D5.A, D25.A, S5.3 (2), S5.4 (2), SW5.3, SW5.4
S6NODE: D6.A, D26.A, S6.3 (2), S6.4 (2), SW6.3, SW6.4
S7NODE: D7.A, D27.A, S7.3 (2), S7.4 (2), SW7.3, SW7.4
S8NODE: D8.A, D28.A, S8.3 (2), S8.4 (2), SW8.3, SW8.4
TX: ATMEGA328P.31 (PD1(TXD)), ATMEGA328P_TQFP.31 (PD1(TXD)), U$2.TX
USB: U$2.USB
VCC: ATMEGA328P.4 (VCC), ATMEGA328P.6 (VCC), ATMEGA328P.18 (AVCC), ATMEGA328P_TQFP.4 (VCC), ATMEGA328P_TQFP.6 (VCC), ATMEGA328P_TQFP.18 (AVCC), C1.2, C_L1.2, C_L2.2, C_L3.2, C_L4.2, LED11.1 (VDD), LED12.1 (VDD), LED13.1 (VDD), LED14.1 (VDD), LED21.1 (VDD), LED22.1 (VDD), LED23.1 (VDD), LED24.1 (VDD), R4.2, R7.2, SCHOTTKY.C, U$2.VCC
XTAL1: ATMEGA328P.7 (PB6(XTAL1/TOSC1)), ATMEGA328P_TQFP.7 (PB6(XTAL1/TOSC1)), C3.2, OSC1.2
XTAL2: ATMEGA328P.8 (PB7(XTAL2/TOSC2)), ATMEGA328P_TQFP.8 (PB7(XTAL2/TOSC2)), C4.1, OSC1.1

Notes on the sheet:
keypad
mode button
indicator LEDs
Pro Trinket 5V
analog/digital pin number in Arduino IDE
VUSB circuitry
Pro Trinket socket
enable pins
encoder signal pins
button signal pins
TQFP footprint (alternate option for QFN footprint)
optional footprints for alternative buttons & diodes
all other 'nodes' are connected as well
alternative to Pro Trinket & VUSB circuitry
optional footprints for LEDs

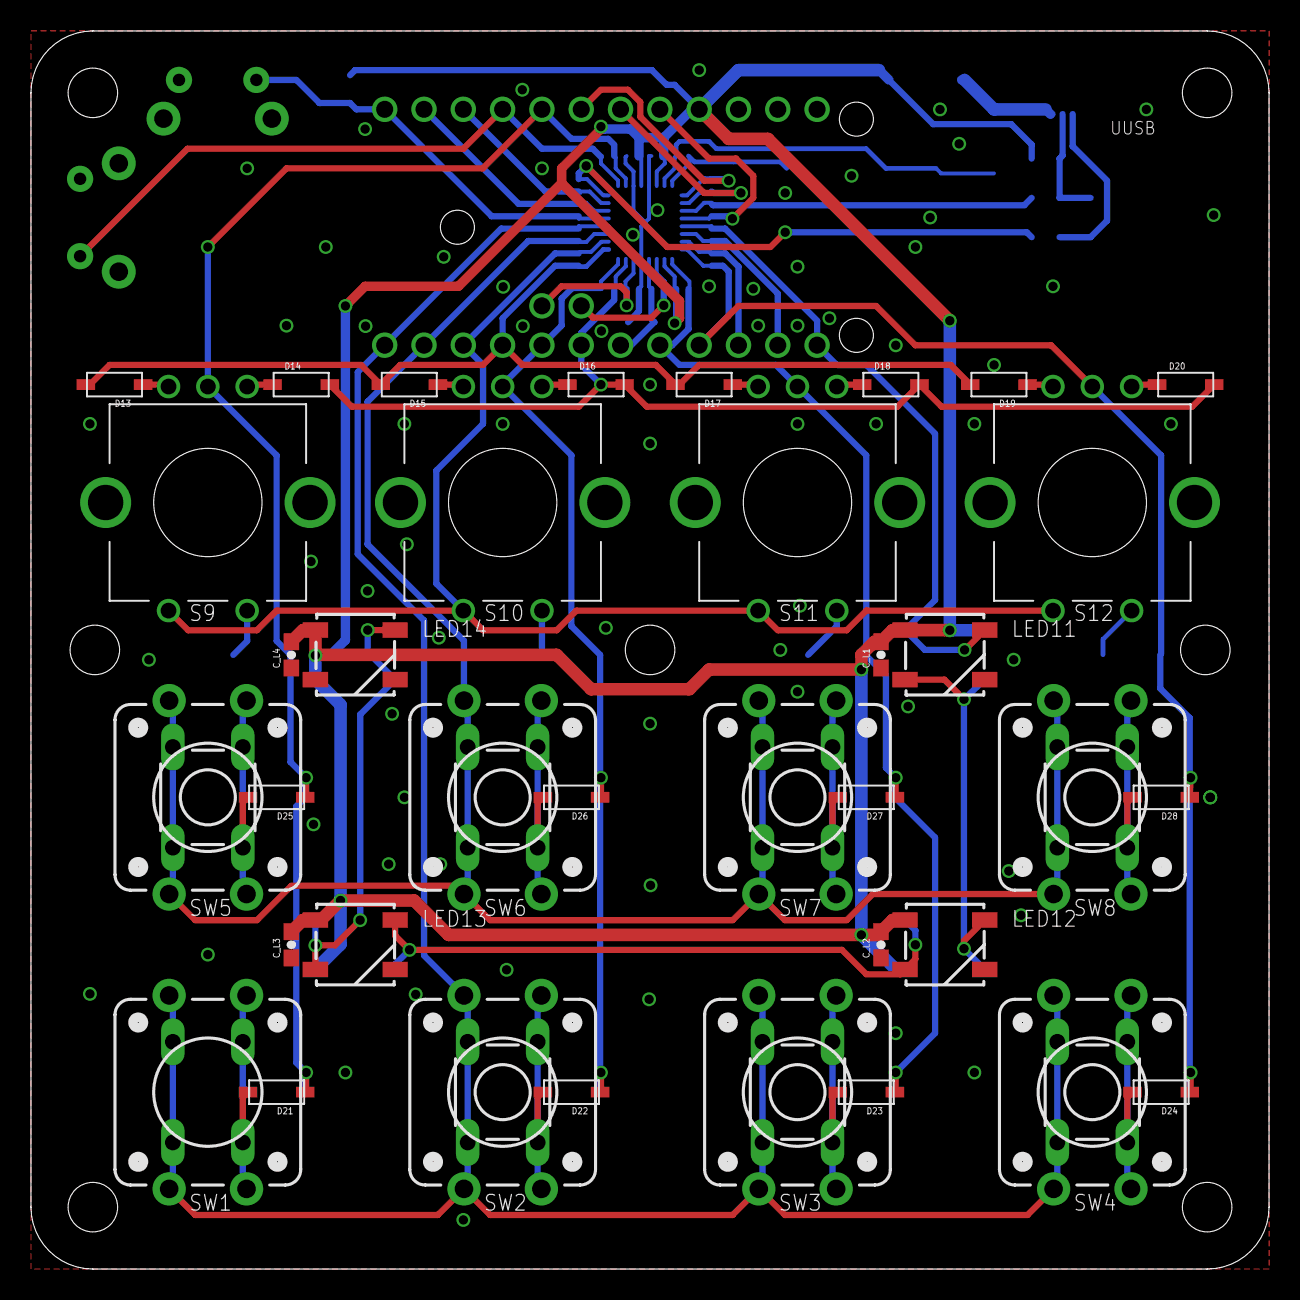
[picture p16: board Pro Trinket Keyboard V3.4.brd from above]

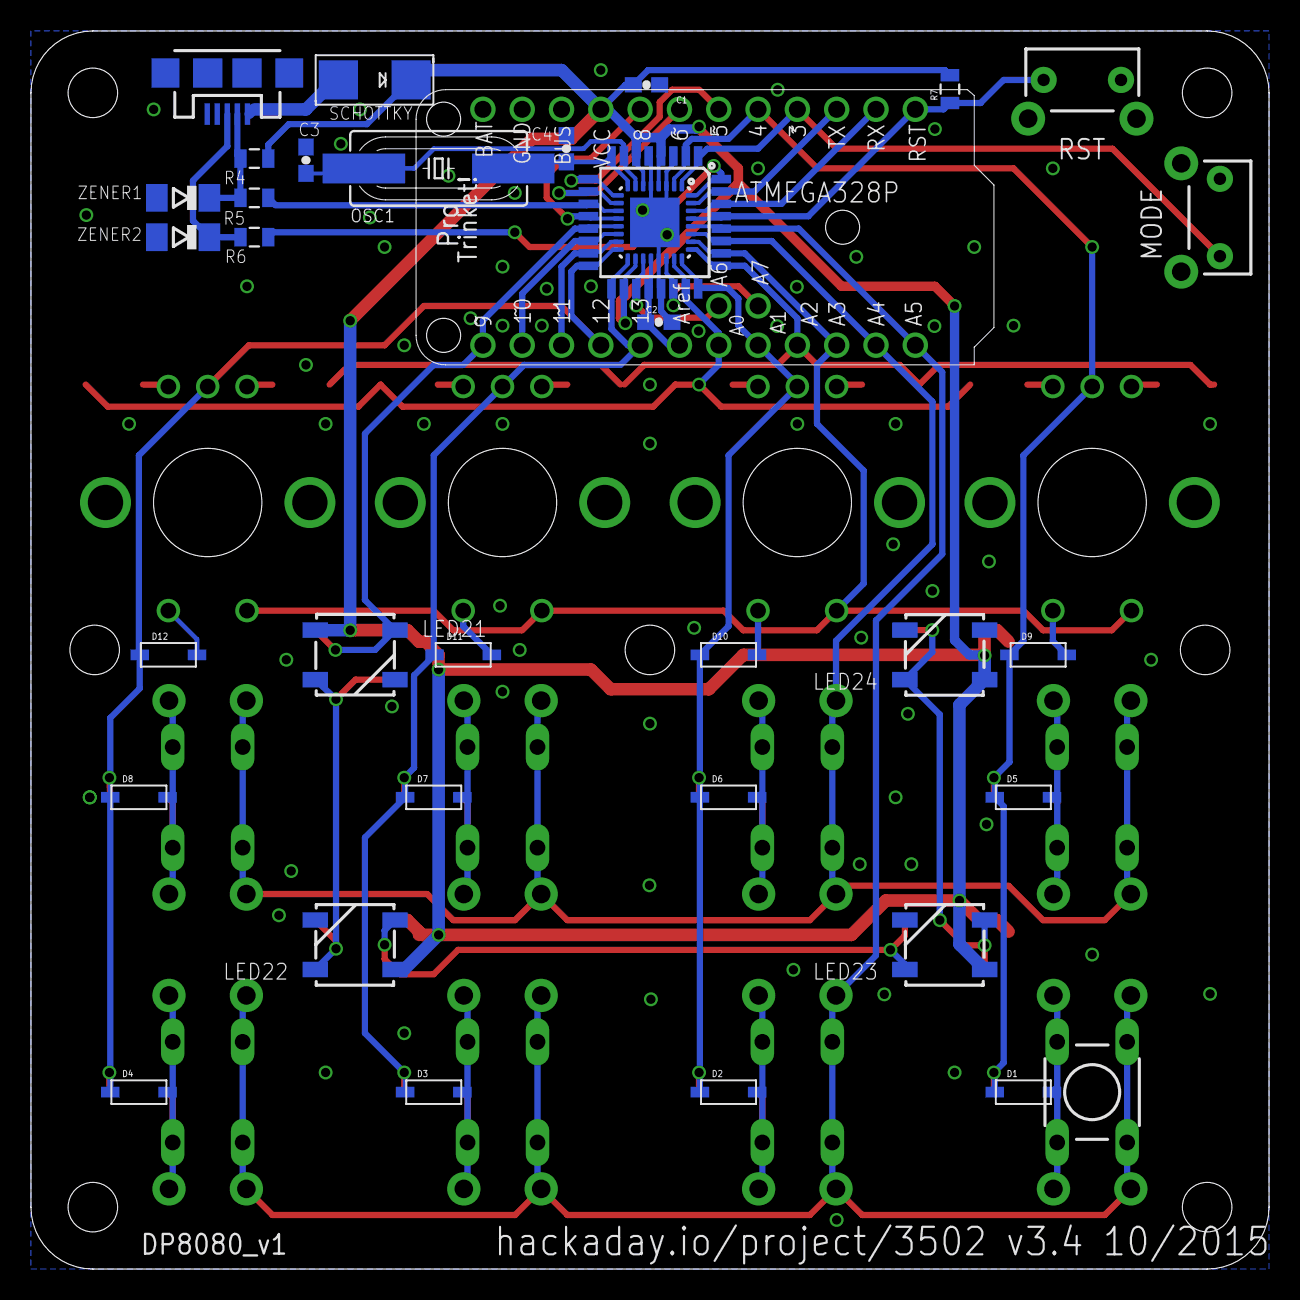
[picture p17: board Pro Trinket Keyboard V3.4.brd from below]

Board: 2 copper layers, 80.0 x 80.0 mm, 79 parts (35 on the bottom side), 54 nets.

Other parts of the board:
U$1: DP8080_V1

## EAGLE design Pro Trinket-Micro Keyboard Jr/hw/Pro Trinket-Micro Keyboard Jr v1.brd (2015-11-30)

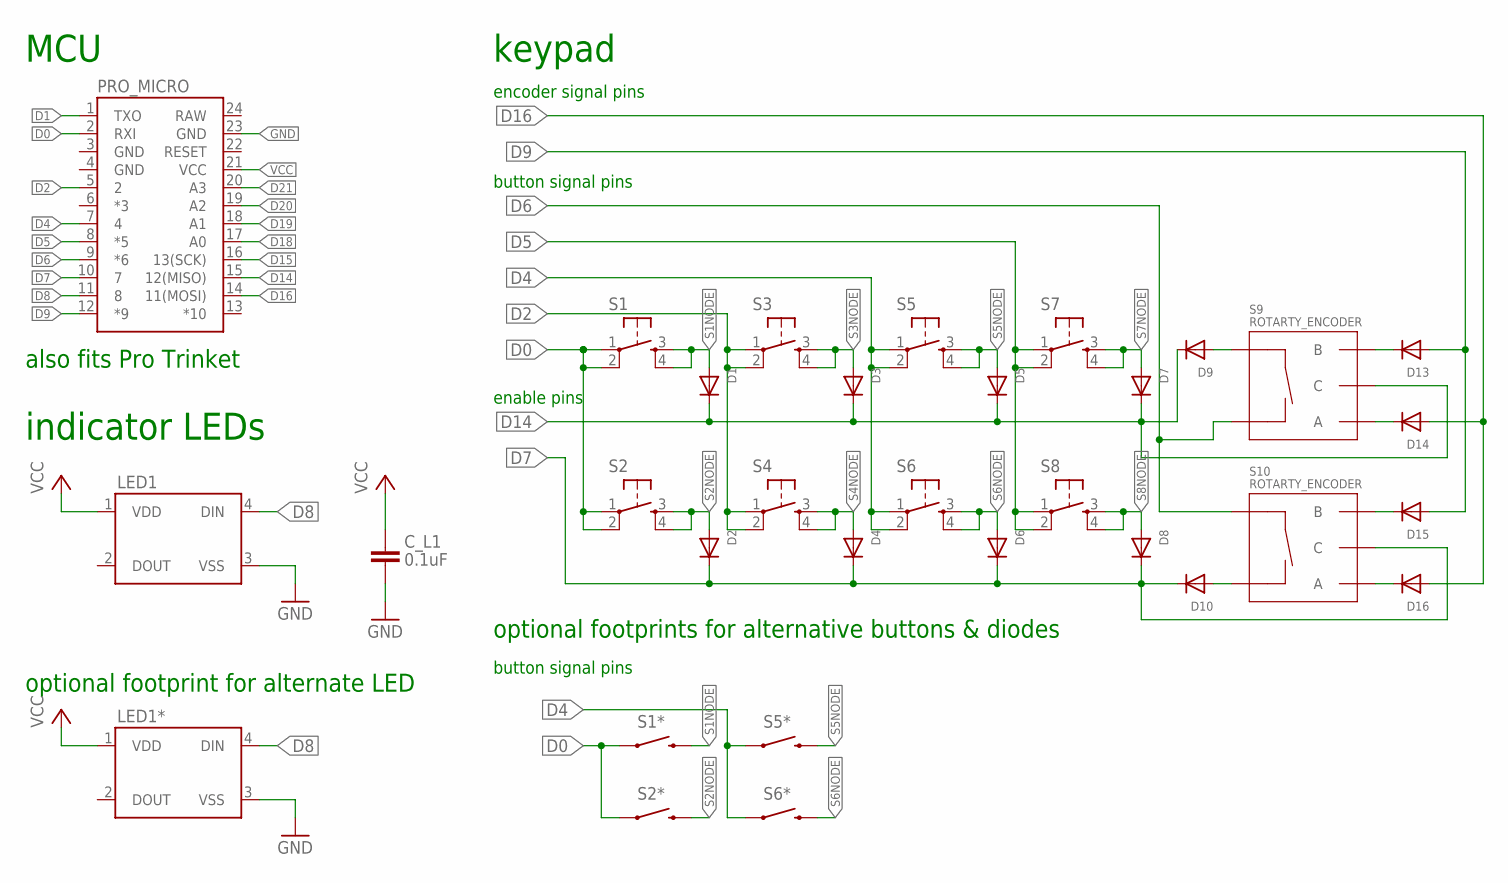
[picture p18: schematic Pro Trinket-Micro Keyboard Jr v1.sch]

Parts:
C_L1: 0.1uF; 0603-CAP
D1, D2, D3, D4, D5, D6, D7, D8, D9, D10, D13, D14, D15, D16: DIODESOD-123; SOD-123
LED1, LED1*: WS2812B
PRO_MICRO: ARDUINO_PRO_MICRO
S1, S2, S3, S4, S5, S6, S7, S8: TACTILE-SWITCH-PTH; TAC-SWITCH-PTH
S1*, S2*, S5*, S6*: SWITCH-MOMENTARY-212MM; TACTILE-PTH-12MM
S9, S10: ROTARTY_ENCODER; ROTARY_ENC_PLAIN

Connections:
D0: PRO_MICRO.2 (RXI), S1.1, S1.2, S1*.1, S1*.2 (1), S2.1, S2.2, S2*.1, S2*.2 (1)
D1: PRO_MICRO.1 (TXO)
D2: PRO_MICRO.5 (2), S3.1, S3.2, S4.1, S4.2
D4: PRO_MICRO.7 (4), S5.1, S5.2, S5*.1, S5*.2 (1), S6.1, S6.2, S6*.1, S6*.2 (1)
D5: PRO_MICRO.8 (*5), S7.1, S7.2, S8.1, S8.2
D6: PRO_MICRO.9 (*6), S9.SW-, S10.SW+
D7: D2.C, D4.C, D6.C, D8.C, D10.C, PRO_MICRO.10 (7), S10.C
D8: LED1.4 (DIN), LED1*.4 (DIN), PRO_MICRO.11 (8)
D9: D13.A, D15.A, PRO_MICRO.12 (*9)
D14: D1.C, D3.C, D5.C, D7.C, D9.C, PRO_MICRO.15 (12(MISO)), S9.C
D15: PRO_MICRO.16 (13(SCK))
D16: D14.A, D16.A, PRO_MICRO.14 (11(MOSI))
D18: PRO_MICRO.17 (A0)
D19: PRO_MICRO.18 (A1)
D20: PRO_MICRO.19 (A2)
D21: PRO_MICRO.20 (A3)
GND: C_L1.1, LED1.3 (VSS), LED1*.3 (VSS), PRO_MICRO.23 (GND)
unnamed: D9.A, S9.SW+
unnamed: D10.A, S10.SW-
unnamed: D16.C, S10.A
unnamed: D15.C, S10.B
unnamed: D14.C, S9.A
unnamed: D13.C, S9.B
S1NODE: D1.A, S1.3, S1.4, S1*.3 (2), S1*.4 (2)
S2NODE: D2.A, S2.3, S2.4, S2*.3 (2), S2*.4 (2)
S3NODE: D3.A, S3.3, S3.4
S4NODE: D4.A, S4.3, S4.4
S5NODE: D5.A, S5.3, S5.4, S5*.3 (2), S5*.4 (2)
S6NODE: D6.A, S6.3, S6.4, S6*.3 (2), S6*.4 (2)
S7NODE: D7.A, S7.3, S7.4
S8NODE: D8.A, S8.3, S8.4
VCC: C_L1.2, LED1.1 (VDD), LED1*.1 (VDD), PRO_MICRO.21 (VCC)

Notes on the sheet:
keypad
indicator LEDs
enable pins
encoder signal pins
button signal pins
optional footprints for alternative buttons & diodes
optional footprint for alternate LED
MCU
also fits Pro Trinket

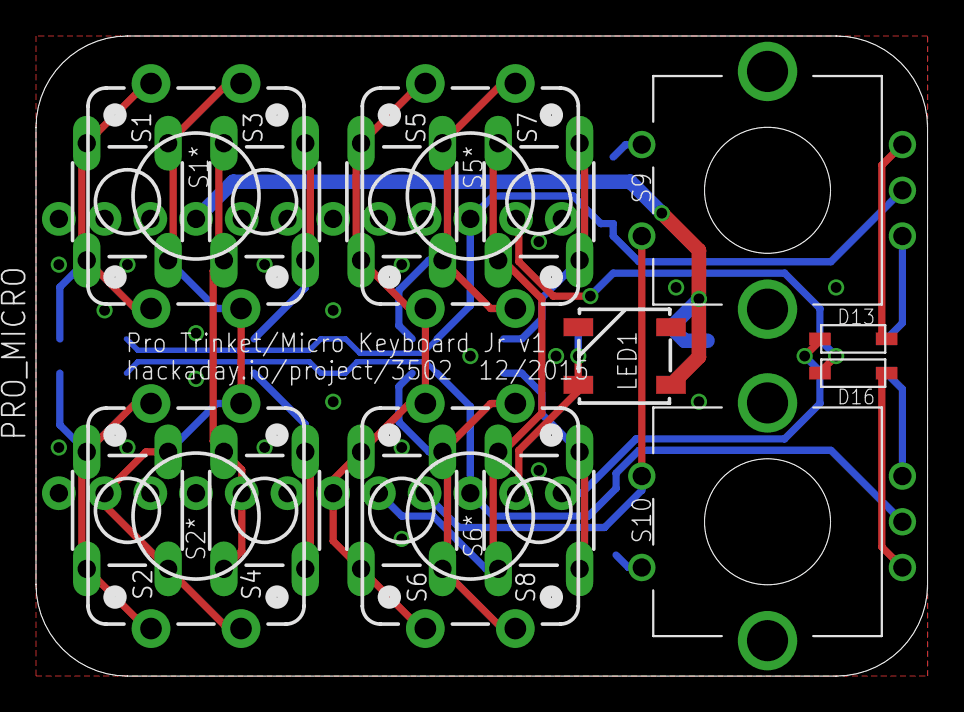
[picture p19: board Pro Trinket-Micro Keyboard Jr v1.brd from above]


Board: 2 copper layers, 49.5 x 35.6 mm, 32 parts (14 on the bottom side), 26 nets.

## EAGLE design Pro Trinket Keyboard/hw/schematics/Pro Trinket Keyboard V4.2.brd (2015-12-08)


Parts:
C1, C2, C3, C4: 0.1uF; 0603-CAP
D1, D2, D3, D4, D5, D6, D7, D8, D9, D10, D11, D12, D13, D14, D15, D16, D17, D18, D19, D20: DIODESOD-123; SOD-123
I2C_BOT_L, I2C_BOT_R, I2C_LEFT_LOW, I2C_LEFT_UP, I2C_RIGHT_LOW, I2C_RIGHT_UP: M04PTH; 1X04
LED1, LED1*, LED2, LED2*, LED3, LED3*, LED4, LED4*: WS2812B
MODE: SWITCH-MOMENTARY-2SIDE_EZ; TACTILE-PTH-SIDEEZ
PRO_TRINKET: PRO_TRINKET; PROTRINKET
R1, R2: RESISTORR805-0805; R805
S1, S2, S3, S4, S5, S6, S7, S8: SWITCH-MOMENTARY-212MM; TACTILE-PTH-12MM
S1*, S2*, S3*, S4*, S5*, S6*, S7*, S8*: TACTILE-SWITCH-PTH; TAC-SWITCH-PTH
S9, S10, S11, S12: ROTARTY_ENCODER; ROTARY_ENC_PLAIN
SCL: SOLDERJUMPER_2WAYS; SJ_3
SDA: SOLDERJUMPER_2WAYS; SJ_3

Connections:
A6: PRO_TRINKET.A6
A7: PRO_TRINKET.A7
AREF: PRO_TRINKET.AREF, SCL.3
BAT+: PRO_TRINKET.BAT+
D0: D1.C, D5.C, D9.C, PRO_TRINKET.RX, S9.C
D1: D2.C, D6.C, D10.C, PRO_TRINKET.TX, S10.C
D3: D14.A, D16.A, D18.A, D20.A, PRO_TRINKET.3 (D3)
D4: D13.A, D15.A, D17.A, D19.A, PRO_TRINKET.4 (D4)
D5: PRO_TRINKET.5 (D5)
D6: LED1.4 (DIN), LED1*.4 (DIN), PRO_TRINKET.6 (D6)
D8: D3.C, D7.C, D11.C, PRO_TRINKET.8 (D8), S11.C
D9: D4.C, D8.C, D12.C, PRO_TRINKET.9 (D9), S12.C
D10: PRO_TRINKET.10 (D10), S1.1, S1.2 (1), S1*.1, S1*.2, S2.1, S2.2 (1), S2*.1, S2*.2, S3.1, S3.2 (1), S3*.1, S3*.2, S4.1, S4.2 (1), S4*.1, S4*.2
D14: PRO_TRINKET.A0, S5.1, S5.2 (1), S5*.1, S5*.2, S6.1, S6.2 (1), S6*.1, S6*.2, S7.1, S7.2 (1), S7*.1, S7*.2, S8.1, S8.2 (1), S8*.1, S8*.2
D15: PRO_TRINKET.A1, S9.SW+, S10.SW+, S11.SW+, S12.SW+
D16: PRO_TRINKET.A2
D17: MODE.2, PRO_TRINKET.A3
D18: PRO_TRINKET.A4, SDA.1
D19: PRO_TRINKET.A5, SCL.1
GND: C1.1, C2.1, C3.1, C4.1, I2C_BOT_L.1, I2C_BOT_R.1, I2C_LEFT_LOW.1, I2C_LEFT_UP.1, I2C_RIGHT_LOW.1, I2C_RIGHT_UP.1, LED1.3 (VSS), LED1*.3 (VSS), LED2.3 (VSS), LED2*.3 (VSS), LED3.3 (VSS), LED3*.3 (VSS), LED4.3 (VSS), LED4*.3 (VSS), MODE.1, PRO_TRINKET.GND
L1NODE: LED1.2 (DOUT), LED1*.2 (DOUT), LED2.4 (DIN), LED2*.4 (DIN)
L2NODE: LED2.2 (DOUT), LED2*.2 (DOUT), LED3.4 (DIN), LED3*.4 (DIN)
L3NODE: LED3.2 (DOUT), LED3*.2 (DOUT), LED4.4 (DIN), LED4*.4 (DIN)
unnamed: D10.A, S10.SW-
unnamed: D9.A, S9.SW-
unnamed: D11.A, S11.SW-
unnamed: D20.C, S12.A
unnamed: D19.C, S12.B
unnamed: D18.C, S11.A
unnamed: D12.A, S12.SW-
unnamed: D16.C, S10.A
unnamed: D15.C, S10.B
unnamed: D14.C, S9.A
unnamed: D13.C, S9.B
unnamed: D17.C, S11.B
NEW: PRO_TRINKET.13 (D13), SDA.3
S1NODE: D1.A, S1.3 (2), S1.4 (2), S1*.3, S1*.4
S2NODE: D2.A, S2.3 (2), S2.4 (2), S2*.3, S2*.4
S3NODE: D3.A, S3.3 (2), S3.4 (2), S3*.3, S3*.4
S4NODE: D4.A, S4.3 (2), S4.4 (2), S4*.3, S4*.4
S5NODE: D5.A, S5.3 (2), S5.4 (2), S5*.3, S5*.4
S6NODE: D6.A, S6.3 (2), S6.4 (2), S6*.3, S6*.4
S7NODE: D7.A, S7.3 (2), S7.4 (2), S7*.3, S7*.4
S8NODE: D8.A, S8.3 (2), S8.4 (2), S8*.3, S8*.4
SCL: I2C_BOT_L.2, I2C_BOT_R.2, I2C_LEFT_LOW.2, I2C_LEFT_UP.2, I2C_RIGHT_LOW.2, I2C_RIGHT_UP.2, R2.1, SCL.2
SDA: I2C_BOT_L.3, I2C_BOT_R.3, I2C_LEFT_LOW.3, I2C_LEFT_UP.3, I2C_RIGHT_LOW.3, I2C_RIGHT_UP.3, R1.1, SDA.2
USB: PRO_TRINKET.USB
VCC: C1.2, C2.2, C3.2, C4.2, I2C_BOT_L.4, I2C_BOT_R.4, I2C_LEFT_LOW.4, I2C_LEFT_UP.4, I2C_RIGHT_LOW.4, I2C_RIGHT_UP.4, LED1.1 (VDD), LED1*.1 (VDD), LED2.1 (VDD), LED2*.1 (VDD), LED3.1 (VDD), LED3*.1 (VDD), LED4.1 (VDD), LED4*.1 (VDD), PRO_TRINKET.VCC, R1.2, R2.2

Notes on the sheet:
keypad
mode button
indicator LEDs
Pro Trinket 5V
enable pins
encoder signal pins
button signal pins
alternative button footprints
alternative LED footprints
pin layout also fits Pro Micro
I²C
SDA
SCL
Pro Trinket
Pro Micro



Board: 2 copper layers, 80.0 x 80.0 mm, 65 parts (35 on the bottom side), 42 nets.

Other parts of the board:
U$1: DP8080_V1

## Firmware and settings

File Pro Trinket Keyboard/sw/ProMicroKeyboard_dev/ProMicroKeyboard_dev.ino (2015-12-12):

/*
Author: S.L.
Amendments by C Hissett
11/2014 initial release
05/2015 updated for changed hardware
06/2015 moved from vusb-for-arduino to ProTrinketHidCombo library
09/2015 updated to utilize multimedia keys, see notes for limitations
11/2015 code forked and amended for ATMega32u4 Arduino boards (exchanging ProTrinketHidCombo.h for Keyboard.h
12/2015 adaptations for hw v3.4a

USB HID device to provide configrable keyboard shortcuts for
various tasks (multimedia control, Photoshop,...)
Inteded for zAdafruit Pro Trinket http://www.adafruit.com/product/2000
  PD2 / digital 2 is D+
  PD7 / digital 7 is D-
Notes:
- Originally intended to be used with keypad library
  http://playground.arduino.cc/code/Keypad
  but was abandoned because of conflicts in the usage of TIMSK0.
- See https://learn.adafruit.com/trinket-usb-volume-knob
  for instructions on rotary encoders
- Originally used VUSB for Arduino https://code.google.com/p/vusb-for-arduino/
  but changed to Adafruit ProTrinketHidCombo library https://github.com/adafruit/Pro-Trinket-Rotary-Encoder
  due to compatibility issues with Arduino 1.6.4. Also allows usage of multimedia keys.
  See https://learn.adafruit.com/pro-trinket-rotary-encoder for more information.
- Limitations:
    # To easily distinguish between 'normal' keys and multimedia keys, KEYCODE_*_CONTROL/SHIFT/ALT/GUI can't be used. Keycodes below 110 (chosen arbitrarily) will be interpreted as 'normal' keys and keycodes above will be interpreted as multimedia keys. In the future, kecodes larger than 234 might be used control mouse.
- Arduino native Keyboard library anly allows for a single modifier which can be solved by adding additional key presses
*/


//include keycodes and USB HID lib
#define ProMicro //or define ProTrinket
#ifdef ProMicro
  #include <Keyboard.h>
  #include "keycodesPM.h"
#endif
#ifdef ProTrinket
  #include <ProTrinketHidCombo.h>
  #include "keycodesPT.h"
#endif
//do the same for pin config
//setup WS2812B lib
#include <Adafruit_NeoPixel.h>


//keypad & encoder definitions
int colPins[] = { 4, 19, 15, 14};  //select pins, driven LOW to select col => btn active LOW
int rowPins[] = {21, 16, 10};      //signal pins, read LOW means btn pressed
int encPins[] = {20, 18};          //encoder signal pins
int const rows = sizeof(rowPins)/sizeof(int);
int const cols = sizeof(colPins)/sizeof(int);

//array for prev btn states to detect distinct presses and releases
int key_prev[rows][cols] = {
  { 1, 1, 1, 1},
  { 1, 1, 1, 1},
  { 1, 1, 1, 1}
};
//array for prev encoder A pin state to detect rotation direction
int enc_prev[cols] = {
  1, 1, 1, 1
};

//misc UI definitions
int const modes = 3;    //number of modes/different keysets
int modeColor[modes][3] = {{16,16,16},{0,0,64},{64,0,0}};   //RGB values for every mode
int mode = 0;           //curent/starting mode
//btn to toggle through modes
int modeBtn = 3;
int modeBtnPrev = 1;
//WS2812B LED to indicate current mode
int ledPin = 9;
int ledCount = 4;
Adafruit_NeoPixel strip = Adafruit_NeoPixel(ledCount, ledPin);

//key sets for different modes
//usb codes for buttons (4x3) in different modes (3). each button can cause 5 keystrokes + optional modifier. see ProTrinketHidCombo.h for more information.
//see additional file for codes. for multiple modifiers combine them with bitwise or.
int usb_codes[modes][rows][cols][6] = {
  //dialpad
  {      // \/ col; {modifier,keycode1,keycode2,keycode3,keycode4,keycode5}
    {{0,KEYCODE_1,0,0,0,0},{0,KEYCODE_2,0,0,0,0},{0,KEYCODE_3,0,0,0,0},{0,KEYCODE_4,0,0,0,0}},    // <-row
    {{0,KEYCODE_5,0,0,0,0},{0,KEYCODE_6,0,0,0,0},{0,KEYCODE_7,0,0,0,0},{0,KEYCODE_8,0,0,0,0}},
    {{0,KEYCODE_9,0,0,0,0},{0,KEYCODE_0,0,0,0,0},{0,KEYCODE_R,0,0,0,0},{0,KEYCODE_G,0,0,0,0}}
  },
  //multimedia
  {
    {{0,MMKEY_MUTE,0,0,0,0},{0,MMKEY_PLAYPAUSE,0,0,0,0},{KEYCODE_MOD_LEFT_CONTROL,KEYCODE_R,0,0,0,0},{0,0,0,0,0,0}},
    //mute,playpause,ctrl+r,
    {{8,KEYCODE_ARROW_LEFT,0,0,0,0},{3,KEYCODE_TAB,0,0,0,0},{KEYCODE_MOD_LEFT_CONTROL,KEYCODE_TAB,0,0,0,0},{8,KEYCODE_ARROW_RIGHT,0,0,0,0}},
    //win+<,ctrl+shift+tab,ctrl+tab,win+>
    {{8,0,0,0,0,0},{KEYCODE_MOD_LEFT_CONTROL,KEYCODE_C,0,0,0,0},{KEYCODE_MOD_LEFT_CONTROL,KEYCODE_V,0,0,0,0},{0,0,0,0,0,0}}
    //win,ctrl+c,ctrl+v,
  },
  //eagle
  {
    {{KEYCODE_MOD_LEFT_ALT,KEYCODE_F2,0,0,0,0},{0,KEYCODE_F2,0,0,0,0},{0,KEYCODE_F6,0,0,0,0},{KEYCODE_MOD_LEFT_CONTROL,KEYCODE_S,0,0,0,0}},
    //view all,redraw,grid toggle,save
    {{KEYCODE_MOD_LEFT_CONTROL,KEYCODE_M,0,0,0,0},{KEYCODE_MOD_LEFT_CONTROL,KEYCODE_G,0,0,0,0},{3,KEYCODE_A,0,0,0,0},{KEYCODE_MOD_LEFT_CONTROL,KEYCODE_D,0,0,0,0}},
    //move,group,add,delete
    {{KEYCODE_MOD_LEFT_CONTROL,KEYCODE_R,0,0,0,0},{3,KEYCODE_R,0,0,0,0},{3,KEYCODE_N,0,0,0,0},{0,KEYCODE_F5,0,0,0,0}}
    //route,ripup,name,view to cursor
  }
};
//encoder actions. 1 enc per col, cw & ccw direction (2) plus optional modifier (2)
//1st is ccw, 2nd is cw
int usb_codes_enc[modes][cols][2][6] = {
  //dialpad
  {
    {{0,KEYCODE_ARROW_DOWN,0,0,0,0},{0,KEYCODE_ARROW_UP,0,0,0,0}},
    {{0,KEYCODE_ARROW_RIGHT,0,0,0,0},{0,KEYCODE_ARROW_LEFT,0,0,0,0}},
    {{0,KEYCODE_1,0,0,0,0},{0,KEYCODE_2,0,0,0,0}},
    {{0,KEYCODE_1,0,0,0,0},{0,KEYCODE_2,0,0,0,0}}
  },
  //multimedia encoders
  {
    {{0,MMKEY_VOL_DOWN,0,0,0,0},{0,MMKEY_VOL_UP,0,0,0,0}},          //volume down, up
    {{0,MMKEY_SCAN_PREV_TRACK,0,0,0,0},{0,MMKEY_SCAN_NEXT_TRACK,0,0,0,0}},      //prev, next track
    {{KEYCODE_MOD_LEFT_CONTROL,KEYCODE_Y,0,0,0,0},{KEYCODE_MOD_LEFT_CONTROL,KEYCODE_Z,0,0,0,0}},                  //undo, redo
    {{0,KEYCODE_ARROW_DOWN,0,0,0,0},{0,KEYCODE_ARROW_UP,0,0,0,0}}   //scroll down, up (arrow keys)
  },
  //eagle
  {
    {{0,KEYCODE_F4,0,0,0,0},{0,KEYCODE_F3,0,0,0,0}},    //zoom
    {{KEYCODE_MOD_LEFT_ALT,KEYCODE_2,0,0,0,0},{KEYCODE_MOD_LEFT_ALT,KEYCODE_1,0,0,0,0}},      //switch sch & brd
    {{3,KEYCODE_U,0,0,0,0},{KEYCODE_MOD_LEFT_CONTROL,KEYCODE_U,0,0,0,0}},      //ratsnest, ripup @;
    {{KEYCODE_MOD_LEFT_CONTROL,KEYCODE_Y,0,0,0,0},{KEYCODE_MOD_LEFT_CONTROL,KEYCODE_Z,0,0,0,0}}       //undo,redo
  }
};

void setup(){
  Serial.begin(9600); // opens serial port, sets data rate to 9600 bps
  
  //set data direction for keypad
  //cols: select, drive low to select
  for(int i=0; i<cols; i++){
    pinMode(colPins[i], OUTPUT);
    digitalWrite(colPins[i], HIGH);
  }
  //rows: sense/read, active low
  for(int i=0; i<rows; i++){
    pinMode(rowPins[i], INPUT_PULLUP);
  }
  //set up encoder inputs
  pinMode(encPins[0], INPUT_PULLUP);
  pinMode(encPins[1], INPUT_PULLUP);
  //mode btn
  pinMode(modeBtn, INPUT_PULLUP);
  //mode LEDs initialization & startup animation
  /*
  for(int i=0; i<leds; i++){
    pinMode(ledPins[i], OUTPUT);
    digitalWrite(ledPins[i], HIGH);
    delay(200);
    digitalWrite(ledPins[i], LOW);
  }
  */
  strip.begin();
  strip.show();

  //USB
  #ifdef ProMicro
    Keyboard.begin();
  #endif
  #ifdef ProTrinket
    TIMSK0&=!(1<<TOIE0);
    TrinketHidCombo.begin();
  #endif

  //while(!TrinketHidCombo.isConnected()){
    //TrinketHidCombo.poll();
  //turn on LED once USB connection is up
  //analogWrite(ledPins[mode], 64);
  for(int i=0; i<ledCount; i++){
    strip.setPixelColor(i, strip.Color(modeColor[mode][0], modeColor[mode][1], modeColor[mode][2]));
  }
  strip.show();
}

void loop(){
  //poll USB
  #ifdef ProTrinket
    TrinketHidCombo.poll();
  #endif

  //poll inputs

  //poll mode button
  if(digitalRead(modeBtn) == 0 && modeBtnPrev == 1){
    modeBtnPrev = 0;
    mode += 1;
    if(mode >= modes){
      mode = 0;
    }
    //change LEDs
    /*
    //turn off all LEDs
    for(int i=0; i<leds; i++){
      digitalWrite(ledPins[i], LOW);
    }
    //turn on current LED if USB is still connected. prevents LEDs being on if PC isn't
    //if(TrinketHidCombo.isConnected()){
      analogWrite(ledPins[mode], 64);
    */
    for(int i=0; i<cols; i++){
      strip.setPixelColor(i, strip.Color(modeColor[mode][0], modeColor[mode][1], modeColor[mode][2]));
    }
    strip.show();
  }
  else if (digitalRead(modeBtn) == 1 && modeBtnPrev == 0){
    modeBtnPrev = 1;
  }

  //cycle through cols
  for(int i=0; i<cols; i++){
    //enable col (active low)
    digitalWrite(colPins[i], LOW);

    //poll rows
    for(int j=0; j<rows; j++){
      //read state of current btn
      int but = digitalRead(rowPins[j]);    //Button Under Test

      //btn was just pressed (0), which means prev state was 1 (unpressed)
      if(but == 0 && key_prev[j][i] == 1){
        //set new prev state
        key_prev[j][i] = 0;

        //execute keystroke
        executeKeystroke(usb_codes[mode][j][i]);
      }
      //key release
      else if(but == 1 && key_prev[j][i] == 0){
        //set new prev state
        key_prev[j][i] = 1;
      }
    }

    //poll encoder
    int A = digitalRead(encPins[0]);
    int B = digitalRead(encPins[1]);
    //detect rotation
    if(A == 0 && enc_prev[i] == 1){
      //change prev state
      enc_prev[i] = 0;

      //determine rotation direction (cw/ccw)
      if(B == 1){
        //ccw rotation

        //execute keystroke
        executeKeystroke(usb_codes_enc[mode][i][0]);
      }
      else if(B == 0){
        //cw rotation

        //execute keystroke
        executeKeystroke(usb_codes_enc[mode][i][1]);
      }
    }
    else if(A == 1 && B == 1){
      //no input on encoder pins
      enc_prev[i] = 1;
    }
    // /poll encoder

    //disable col
    digitalWrite(colPins[i], HIGH);

    delayMicroseconds(250);    //software debounce
    //delay(250);
  }
  // /cycle through cols
}

//differentiate between keycode and multimedia keycode
void executeKeystroke(int* keycombo){
  //Serial.println(keycombo[1]);
  if(keycombo[1] < 110){    // || keycombo[1] == 224 || keycombo[1] == 225 || keycombo[1] == 227 || keycombo[1] == 228 || keycombo[1] == 230){
    if(keycombo[0]){        //press modifier only if there is one
      #ifdef ProMicro
        Keyboard.press(keycombo[0]);
      #endif
    }
    #ifdef ProMicro
      Keyboard.press(keycombo[1]);
      Keyboard.releaseAll();      //release button(s)
    #endif
    #ifdef ProTrinket
      TrinketHidCombo.pressKey(keycombo[0], keycombo[1]);
      TrinketHidCombo.pressKey(0, 0);      //release button(s)
    #endif
  }
  else if(keycombo[1] >= 110 && keycombo[1] < 235){
    #ifdef ProMicro
      Keyboard.press(keycombo[1]);
      Keyboard.releaseAll();      //release button(s)
    #endif
    #ifdef ProTrinket
      TrinketHidCombo.pressMultimediaKey(keycombo[1]);
      TrinketHidCombo.pressMultimediaKey(0);      //release button
    #endif
  }
}

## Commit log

2015-01-01 added sketch and schematics
    [Pro Trinket Keyboard.sch]
2015-01-01 added schematics image
2015-01-16 added V2 schematic w/ more details
    [Pro Trinket Keyboard V2.sch]
2015-01-16 added V2 schematic image
2015-01-22 Corrections in sketch comments, added keycodes.txt
    Added keycodes.txt which contains a collection of codes
    [ProTrinketUsbKeyboard.ino]
2015-02-15 updated schematic, added layout
    [Pro Trinket Keyboard V3.1.brd, Pro Trinket Keyboard V3.1.sch]
2015-02-16 added schematic and layout images
2015-02-16 changed filename
    [Pro Trinket Keyboard V1.sch]
2015-03-28 updated schematic and layout
    [Pro Trinket Keyboard V3.1.brd, Pro Trinket Keyboard V3.1.sch]
2015-03-29 added case templates
    [SoBv1-DP8080-case-top.dxf, SoBv1-DP8080-case-top.skp, SoBv1-DP8080-template.skp]
2015-09-26 added v3.3 schematics & board
    [Pro Trinket Keyboard V3.3.brd, Pro Trinket Keyboard V3.3.sch]
2015-09-26 added v3.2 schematic & board
    [Pro Trinket Keyboard V3.2.brd, Pro Trinket Keyboard V3.2.sch]
2015-10-20 added v3.4 schematics & board
    [Pro Trinket Keyboard V3.4.brd, Pro Trinket Keyboard V3.4.sch]
2015-10-20 updated board file
    [Pro Trinket Keyboard V3.4.brd]
2015-10-29 added v3.4 a schematic & board
    [Pro Trinket Keyboard V3.4 a.brd, Pro Trinket Keyboard V3.4 a.sch]
2015-10-29 updated board files
    [Pro Trinket Keyboard V3.4 a.brd, Pro Trinket Keyboard V3.4.brd]
2015-10-30 added v3.4a gerbers
2015-10-30 updated gerbers
2015-11-30 added v4 schematics
    [Pro Trinket Keyboard V4.brd, Pro Trinket Keyboard V4.sch]
2015-11-30 initial Pro Trinket/Micro Keyboard Jr release
    [Pro Trinket-Micro Keyboard Jr v1.brd, Pro Trinket-Micro Keyboard Jr v1.sch]
2015-12-05 added v4.1 schematics & board
    [Pro Trinket Keyboard V4.1.brd, Pro Trinket Keyboard V4.1.sch]
2015-12-08 renamed v4
    [Pro Trinket Keyboard V4.0.brd, Pro Trinket Keyboard V4.0.sch]
2015-12-08 added v4.2 schematics & board
    [Pro Trinket Keyboard V4.2.brd, Pro Trinket Keyboard V4.2.sch]
2015-12-10 removed erroneous hardware versions
    [Pro Trinket Keyboard V3.4 a.brd, Pro Trinket Keyboard V3.4 a.sch, Pro Trinket Keyboard V4.1.brd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]
2015-12-10 restructured repo
    [Pro Trinket Keyboard V1.sch, Pro Trinket Keyboard V2.sch, Pro Trinket Keyboard V3.1.brd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]
2015-12-10 re-restructured repo
    [Pro Trinket Keyboard V1.sch, Pro Trinket Keyboard V2.sch, Pro Trinket Keyboard V3.1.brd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]
2015-12-11 added accessory boards
    [accessory 40x40_temp.brd, accessory 40x40_temp.sch, accessory 40x80_temp.brd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]

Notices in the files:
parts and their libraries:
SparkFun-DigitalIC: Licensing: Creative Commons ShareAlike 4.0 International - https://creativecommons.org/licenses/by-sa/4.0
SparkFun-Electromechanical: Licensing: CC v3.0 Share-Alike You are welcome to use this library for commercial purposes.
